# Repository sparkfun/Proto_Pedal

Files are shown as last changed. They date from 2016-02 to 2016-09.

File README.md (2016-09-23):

SparkFun Proto Pedal
========================================

SparkFun Proto Pedal

[*SparkFun Proto Pedal*](https://www.sparkfun.com/products/13124)

[*SparkFun Proto Pedal Chassis*](https://www.sparkfun.com/products/13967)

The SparkFun Proto Pedal is breatboard featuring prewired I/O boilerplate for building guitar stompboxes.  We also offer a matching predrilled chassis.

_**If you're looking for the Teensy Project Sketches**_ [they're here](https://github.com/sparkfun/Proto_Pedal/tree/master/projects/teensy-based).  Please remember to check the individual sketches for further notes and details in their respective `README.md` files.

Repository Contents
-------------------

* **/Hardware** - Eagle design files (.brd, .sch)
* **/Mechanical** - Enclosure files and related information
* **/Production** - Production panel files (.brd)
* **/Projects** - Example circuits build on the Proto Pedal <PRODUCT NAME>

Documentation
--------------
* **[Proto Pedal Assembly and Theory Guide](https://learn.sparkfun.com/tutorials/proto-pedal-assembly-and-theory-guide)** - Information to help get started.
* **[Chassis Hookup Guide](https://learn.sparkfun.com/tutorials/proto-pedal-chassis-hookup-guide)** - Drilling and painting the enclosure.
* **[Analog Equalizer Project](https://learn.sparkfun.com/tutorials/proto-pedal-example-analog-equalizer-project)** - the gyrator based two-band EQ example.
* **[Teensy-Audio based Programmable Digital Pedal](https://learn.sparkfun.com/tutorials/proto-pedal-example-programmable-digital-pedal)** - building a DSP development platform

Product Versions
----------------
* [SparkFun Proto Pedal](https://www.sparkfun.com/products/13124)
* [SparkFun Proto Pedal Chassis](https://www.sparkfun.com/products/13967)

Version History
---------------
* [441c191](https://github.com/sparkfun/Proto_Pedal/commit/441c1917a6b56c2a821627207be28ff88913c089) - Initial Release

License Information
-------------------

This product is _**open source**_!

Please review the LICENSE.md file for license information.

If you have any questions or concerns on licensing, please contact techsupport@sparkfun.com.

Distributed as-is; no warranty is given.

- Your friends at SparkFun.

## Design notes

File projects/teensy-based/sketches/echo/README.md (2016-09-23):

# Echo Pedal

This sketch runs on a Teensy that has been embeded into a proto pedal.

**Important**: build this in a non-optimized target mode.  We were using the plain 72 MHz mode.  If you feel strongly about optimization, you'll need to slightly decrease the delay buffer size, as specified by the LEN macro.  Optimization apparently trades RAM for execution speed.

The effect emulates a vintage style tape echo, by degenerating the repeats with hipass and lopass filters.  The delay feedback can to go above unity gain, and the lopass filter has a Q control, allowing buildup of repeat artifacts.

The demo expects 5 knobs:

* Delay length at A1 -- how long it takes new input to reach the output
* Feedback level at A7 -- controls the number of echoes
* Highpass frequency at A1 -- Feedback filter highpass frequency
* Highpass resonance at A6 -- Feedback filter highpass resonance, effectively a bass boost
* Lowpass frequency at A7 -- Feedback filter lowpass frequency

Iff'n ya build it with **6** knobs, then you've got a control for the Lowpass Q, too.

The Highpass resonance contributes to the feedback.  Both it and the feedback control can cause the effect to run away.

## Directory contents:

* echo.ino -- The sketch.  Requires teensyduino
* readme.md -- This file.
* mod-delay.cpp/.h -- the delay line object...not yet mature enough to be officially contributed to Teensy Audio.
* cubic-distort.cpp/.h -- a vestigial soft-clipping distortion block.

## Performance Notes

It can be a fun effect, but it's got some ugly details.

* The distortion in the feedback loop wasn't especially useful.  The mixers already use saturating math, so they hard clip.
* There's also a white noise block feeding the input mixer, but it's usually turned off.  It's possible to introduce an almost inaudible amount, to get it to run away with no other input.
* The delay line gets wonky & distorted if the modulation input is discontinuous.  We do several things to help smooth it.
  * We throw away the noisy bottom LSBs of that ADC channel.
  * We're using a DC block to generate the timing signal for the delay, and setting the ramp time parameter to be longer than necessary.  If you want to make things sound more rubbery, turn that time way up...
  * We keep track of the last value sent to that DC block, so we aren't calling it continually, resetting the time parameter.

There's also the issue of noise floor performance.  What we've learned so far

* Having the USB port connected contributes to the 60/120 Hz in the background.
* Having the USB port connected & talking to a serial app causes even more noise.

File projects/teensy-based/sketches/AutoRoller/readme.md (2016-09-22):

# AutoRoller Pedal

This sketch runs on a Teensy that has been embeded into a proto pedal.

The effect has an input filter for tone control, and output low-pass filter for effect, and a modulation source consisting of a sine wave generator with rate dependent on input peak values, so the louder you play the more wah-wahs happen.

The demo expects 5 knobs:

* Hi knob at A3 -- Input filter high tones
* Lo knob at A2 -- Input filter low tones
* Tone knob at A1 -- Output filter cutoff and resonance.  CCW is low filter high Q, CW is high filter low Q
* Depth knob at A6 -- Sets modulation depth
* Speed knob at A7 -- Sets modulation osc rate

Directory contents:

* AutoRoller.ino -- The sketch.  Requires teensyduino
* AutoRollerAudioProject.png -- A picture of the Audio Tool workspace
* AutoRollerAudioProject.txt -- The output data that corresponds with the graphic.  Note:  This may differ from the sketch but should always match the graphic.  This is so you can modify the sketch but still have the source Audio Tool project, until you are happy with the changes and the png/txt can be updated.
* readme.md -- This file.

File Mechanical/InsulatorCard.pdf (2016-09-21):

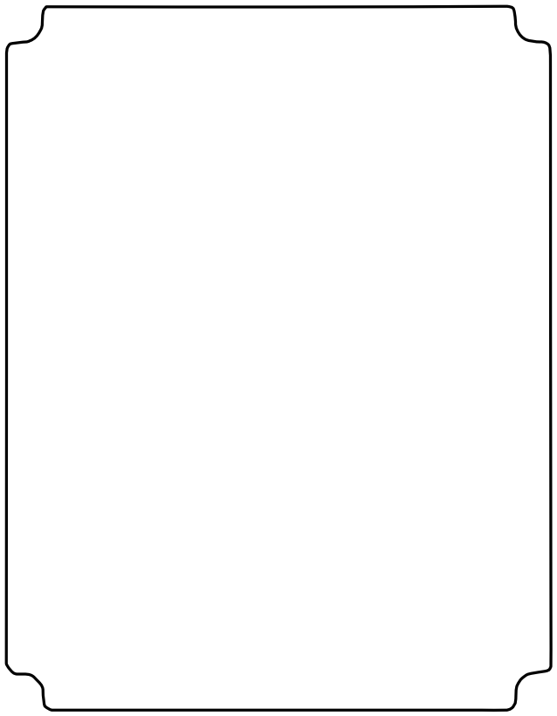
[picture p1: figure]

Proto Pedal Insulator Card

Select “Actual Size” when printing

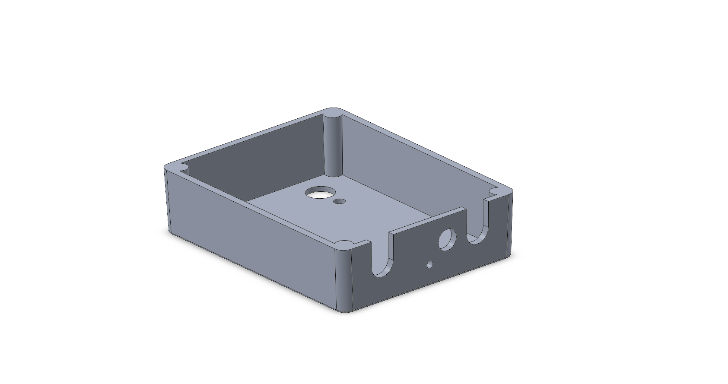
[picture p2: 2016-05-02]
Mechanical/solidworks/case_w_cutouts_model.PNG

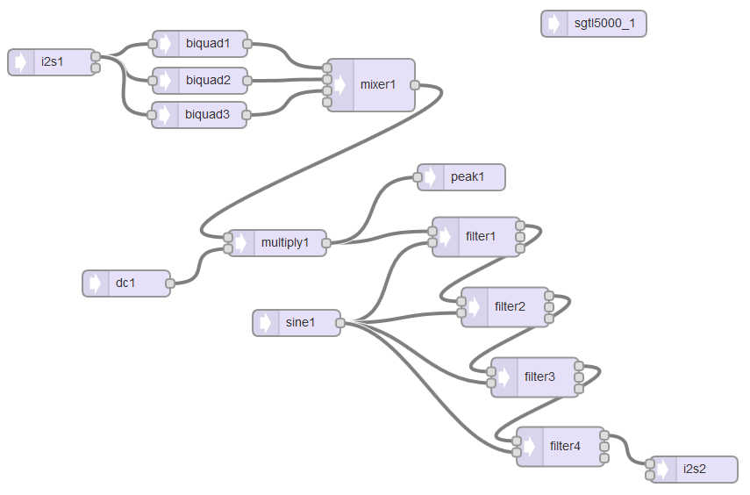
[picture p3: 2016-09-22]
projects/teensy-based/sketches/AutoRoller/AutoRollerAudioProject.png

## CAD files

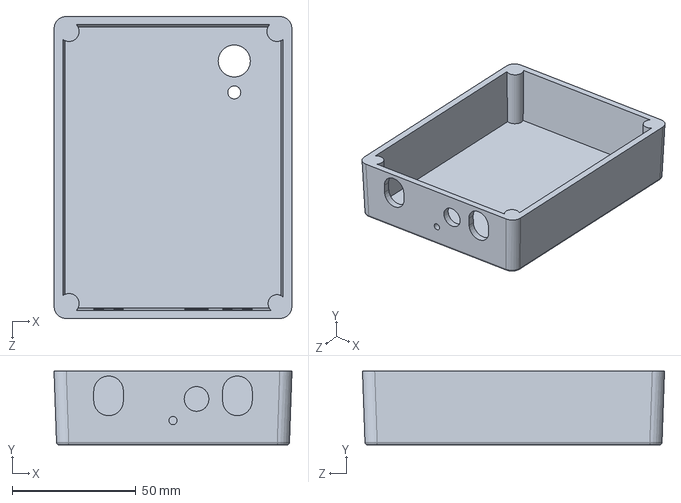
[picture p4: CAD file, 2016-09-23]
Mechanical/solidworks/case_w_cutouts_model_2.SLDPRT
96.2 x 29.8 x 122.1 mm

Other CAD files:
Mechanical/CaseWCutoutsModel.FCStd

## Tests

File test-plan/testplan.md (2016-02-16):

#Proto Pedal Test Plan.

## Prologue

Assemble the protopedal by soldering the PTH components to the PCB.  If you're intending to interface with a case, it's best to use the case as an assembly jig, to hold the TRS jacks and stomp switch.  Be sure the following have been connected:

* 2x TRS jacks
* 9V battery snap with regard for color coding.
* Barrel jack.

## Background

*The stuff it's easy to forget when testing this device*

Power circuits are completed by connecting a 1/4" TS jack  to the input terminal.  The sleeve of the jack bridges the ring terminal to ground, completing the power circuit.

The barrel jack is sleeve-positive, tip-negative, as per the Roland/Boss standard.

The barrel jack should disconnect the 9V battery when it's connected.  We'll test this below!

## Materials

* Multimeter with continuity, VDC and IDC modes.
* Adjustable DC power supply with alligator clip wires and Ammeter display. 
	* If not stated in test, configure supply for 9VDC output, with 25 mA current limit.   
* Barrel jack to raw wire pigtail, with *tip* and *barrel* clearly marked.
* 1/4" TS jack (this can be a loose jack, or on a TS cable).  *Be certain that it is not a TRS jack!*

## Power Related Tests

1. Sanity check against obvious shorts
	* Measure continuity between VCC and ground pads.
	* **Criteria:** should read open-circuit from VCC to Ground. 

2. Verify input jack form ground connection
	* Measure continuity from TP4 (input ring, adjacent to input test point) to GND.
	* **Criteria:**  should measure open.
	* Connect TS jack to input.
	* Measure continuity from TP4 to GND.
	* **Criteria:** Should measure short.

3. Verify VAUX is floating
	* Measure continuity from Vaux to VCC
	* **Criteria:** should measure open
	* Measure continuity from Vaux to GND
	* **Criteria:** should measure open 

3. Verify battery snap polarity.
	* Connect power supply to 9V battery snap.  
		* The larger terminal is +V
		* The smaller terminal is ground
	* Set power supply to current limit at 25 mA.
	* Switch supply on. 
	* **Criteria:** Supply should indicate no current flowing.
	* Connect 1/4" TS jack to input.
	* Measure voltage between VCC and GND.
	* **Criteria:** Should measure supply voltage between VCC and GND
	* Switch the stomp switch.
	* **Criteria:** SMT LED should toggle on and off
	* **Criteria:** While LED is on, supply current should read ~5 mA.
	* Turn power supply off, remove input jack, disconnect battery snap.

4.  Verify 9V battery reverse polarity protection
	* Connect power supply to 9V battery snap, now reversed.  
		* The larger terminal is Ground
		* The smaller terminal is +V
	* Set power supply to current limit at 25 mA.
	* Switch supply on. 
	* **Criteria:** Supply should indicate no current flowing.
	* Connect 1/4" TS jack to input.
	* Measure voltage between VCC and GND.
	* **Criteria:** Should measure at most 10 mV DC, supply indicating no measurable current.
	* Switch the stomp switch.
	* **Criteria:** SMT LED should remain dark
	* Turn power supply off, remove input jack, disconnect battery snap.

5. Verify barrel jack polarity.
	* Connect power supply to barrel jack with pigtails  
		* Barrel is +V
		* Tip is ground
	* Set power supply to current limit at 25 mA.
	* Switch supply on. 
	* **Criteria:** Supply should indicate no current flowing.
	* Connect 1/4" TS jack to input.
	* Measure voltage between VCC and GND.
	* **Criteria:** Should measure supply voltage between VCC and GND
	* Switch the stomp switch.
	* **Criteria:** SMT LED should toggle on and off
	* **Criteria:** While LED is on, supply current should read ~5 mA.
	* Turn power supply off, remove input jack, disconnect battery snap.

6. Verify barrel jack reverse polarity protection
	* Connect power supply to barrel jack with pigtails  
		* Barrel is ground
		* Tip is +V
	* Set power supply to current limit at 25 mA.
	* Switch supply on. 
	* **Criteria:** Supply should indicate no current flowing.
	* Connect 1/4" TS jack to input.
	* Measure voltage between VCC and GND.
	* **Criteria:** Should measure at most 10 mV DC, supply indicating no measurable current.
	* Switch the stomp switch.
	* **Criteria:** SMT LED should remain dark
	* Turn power supply off, remove input jack, disconnect battery snap.

7. Verify Barrel Jack Defeats battery. 
	* Connect power supply to 9V battery snap.  
		* The larger terminal is +V
		* The smaller terminal is ground
	* Disconnect barrel jack pigtails from all connections 
	* Insert TS jack into input.
	* Toggle stomp switch until SMT LED comes on.
	* **Criteria:** Supply should indicate ~5 mA DC draw.
	* Insert disconnected barrel into socket.
	* **Criteria:** Supply should indicate 0 mA, LED should go dark.
	* Remove barrel from socket.
	* **Criteria:** LED should illuminate, current returns to ~5 mA. 
 
8. Verify Power Input Range
	* Connect power supply to barrel jack with pigtails  
		* Barrel is +V
		* Tip is ground
	* Plug TS into input.
	* Turn on power supply at 9 VDC.
	* Toggle stomp switch until LED comes on.
	* Slowly ramp PSU up to 18 VDC.
	* **Criteria:** No catastrophic failure, excess heat or excess current draw (typical current draw will be about ~15 mA).  
	
## Switching Related Tests.

1. Prerequesite configuration
	* These teses assume that the DUT has already passed the power section tests.  They also share a common setup:
		* TS connector plugged into intput jack.
		* 9VDC connected via barrel connector
			* barrel is +9VDC
			* tip is ground
		* These tests will call for DUT to switch between active and bypass states.  The SMT LED is illuminated when the DUT is in the active state. 

1. Verify Bypass state is functional
	* Set switch to bypass. SMT LED will be off.
	* Measure resistance from input tip connection to left side of C1 (at lower left corner of PCB) 
	* **Criteria:** External side of C1 is floating WRT input tip
	* Measure resistance from input tip to output tip.
	* **Criteria:** tip-to-tip shows continuity.
	* Measure resistance from left side of C1 to ground
	* **Criteria:** LHS of C1 continuous with ground
	* Measure RHS of C2  (adjacent to battery leads) to tip of output
	* **Criteria:** RHS of C2 is floating WRT output tip
	* Measure RHS of C2 to ground
	* **Criteria:** RHS of C2 is 1Meg to ground.  
	* 
2. Verify active state is functional
	* Set switch to active state.  SMT LED will illuminate
	* Measure voltage between RHS of R4 (PTH resistor marked "BRT") and ground
	* **Criteria:** Vcc (~9VDC) present at RHS of R4.
	* Measure resistance from input tip to ground.
	* **Criteria:** Input tip is is 1Meg to ground.  
	* Measure resistance from input tip to LHS C1.
	* **Criteria:** Input tip is contonuous with LHS C1
	* Measure resistance input tip to output tip
	* **Criteria:** Resistance tip-to-tip is 2 Meg.
	* Measure resistance RHS of C2 to output tip
	* **Criteria:** Output tip is contonuous with RHS C2
	* Measure resistance output tip to ground 
	* **Criteria:** Output tip is is 1Meg to ground.
3. Verify SJ1 defeats SMT LED.
	* Remove power.
	* Clear solder jumper SJ1

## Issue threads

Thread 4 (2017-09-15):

Error compiling for Teensy 3.2 in Arduino 1.6.133

mswartz, 2017-09-15:
Hi, thanks for a fun tutorial! Got the hardware running, am trying to use some of the software examples. Throughput works fine, but I'm running into this problem with the echo sketch:

```echo: In function 'void loop()':
echo:178: warning: unused variable 'next_on'
   static bool next_on = true;
               ^
/Applications/Arduino.app/Contents/Java/hardware/tools/arm/bin/../lib/gcc/arm-none-eabi/4.8.4/../../../../arm-none-eabi/bin/ld: /var/folders/t2/8mc1sfxx51d39b6_826qt5c00000gn/T/arduino_build_49085/echo.ino.elf section `.bss' will not fit in region `RAM'
/Applications/Arduino.app/Contents/Java/hardware/tools/arm/bin/../lib/gcc/arm-none-eabi/4.8.4/../../../../arm-none-eabi/bin/ld: region `RAM' overflowed by 1280 bytes
collect2: error: ld returned 1 exit status
Multiple libraries were found for "SD.h"
 Used: /Applications/Arduino.app/Contents/Java/hardware/teensy/avr/libraries/SD
 Not used: /Applications/Arduino.app/Contents/Java/libraries/SD
Error compiling for board Teensy 3.2 / 3.1.```

Any ideas for how to fix this?

Jacquot-SFE, 2017-09-15:
I've seen this before.  Two things to try.

First, make sure you've got a non-optimized target selected in the "tools->cpu speed" menu.  The optimized builds supposedly run faster, but use more RAM.  You don't need the computational cycles, but more RAM means longer max delay time, which you probably _do_ want.

Second, if that fails (the internals may have changed since I wrote the sketch), take the number in the error message (ie: the 1280 bytes), and subtract it from the LEN constant.

mswartz, 2017-09-15:
Ah, thanks! I reduced LEN to `0x06300` and it worked, albeit with a low memory warning. Thanks for the quick help.

mswartz, 2017-09-15:
Also just confirmed that changing the CPU speed works as well. Great tips, thanks!

Closed 2017-09-15.

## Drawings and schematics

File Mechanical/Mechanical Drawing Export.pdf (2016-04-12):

# FRONT VIEW (VORDERSEITE)

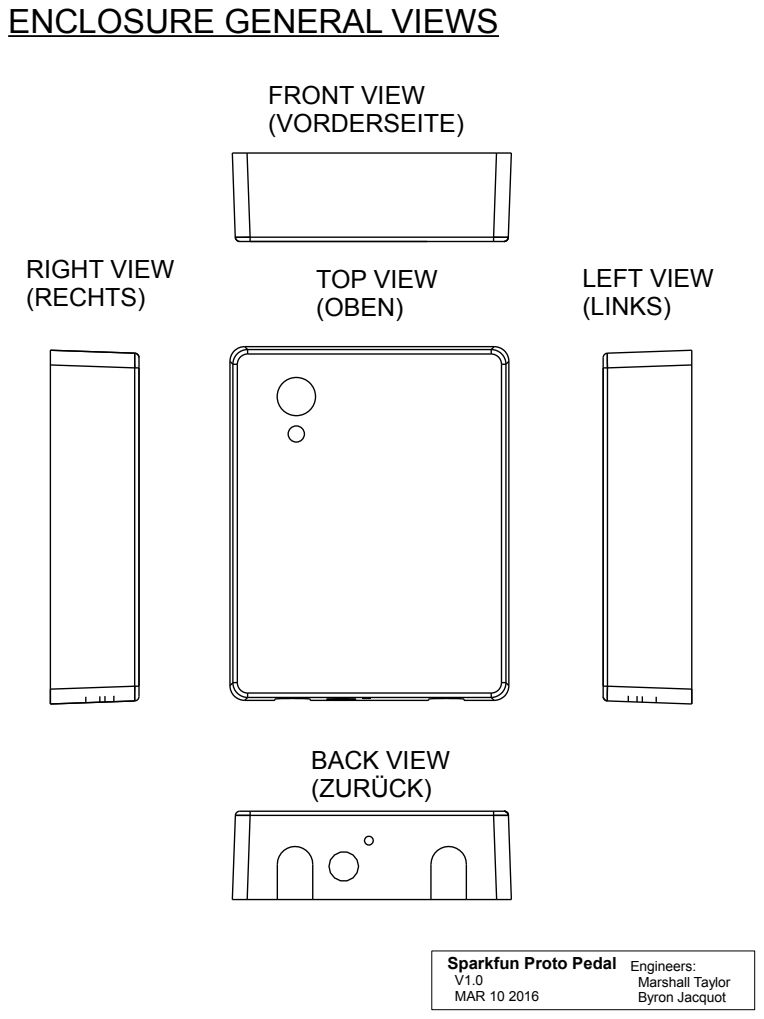
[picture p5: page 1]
RIGHT VIEW (RECHTS); LEFT VIEW (LINKS); BACK VIEW (ZURÜCK); TOP VIEW (OBEN); Engineers: Marshall Taylor Byron Jacquot; Sparkfun Proto Pedal V1.0 MAR 10 2016

ENCLOSURE GENERAL VIEWS

# ENCLOSURE DETAIL

# TOP VIEW

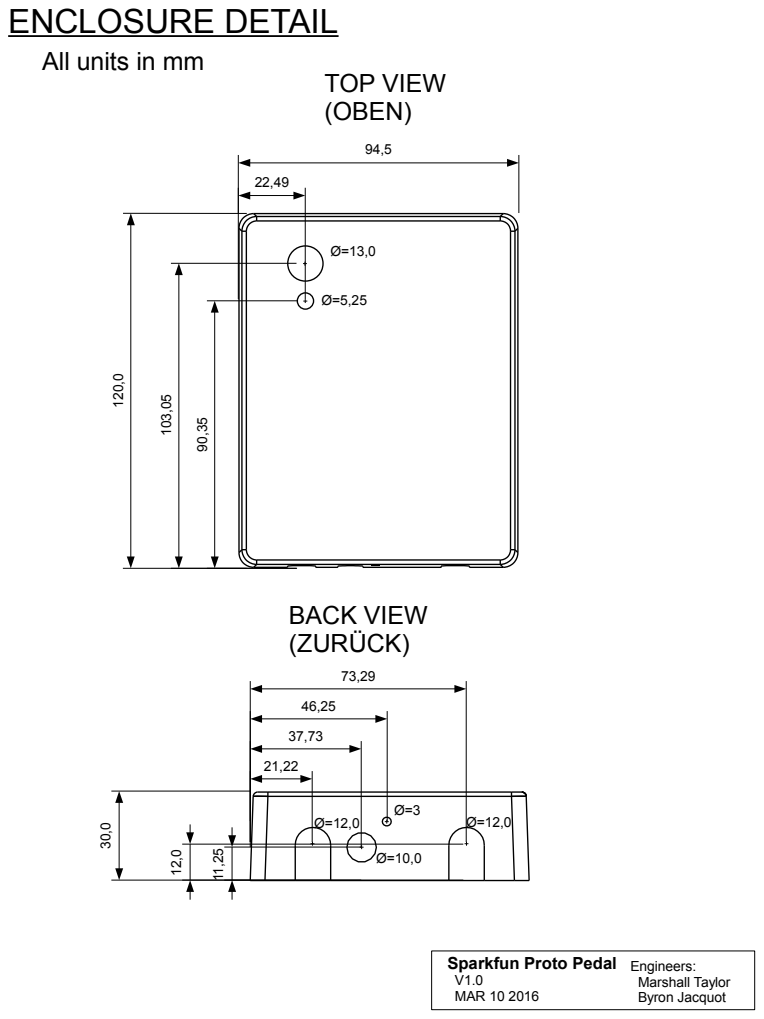
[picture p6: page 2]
BACK VIEW (ZURÜCK); (OBEN); Engineers: Marshall Taylor Byron Jacquot; Sparkfun Proto Pedal V1.0 MAR 10 2016

All units in mm

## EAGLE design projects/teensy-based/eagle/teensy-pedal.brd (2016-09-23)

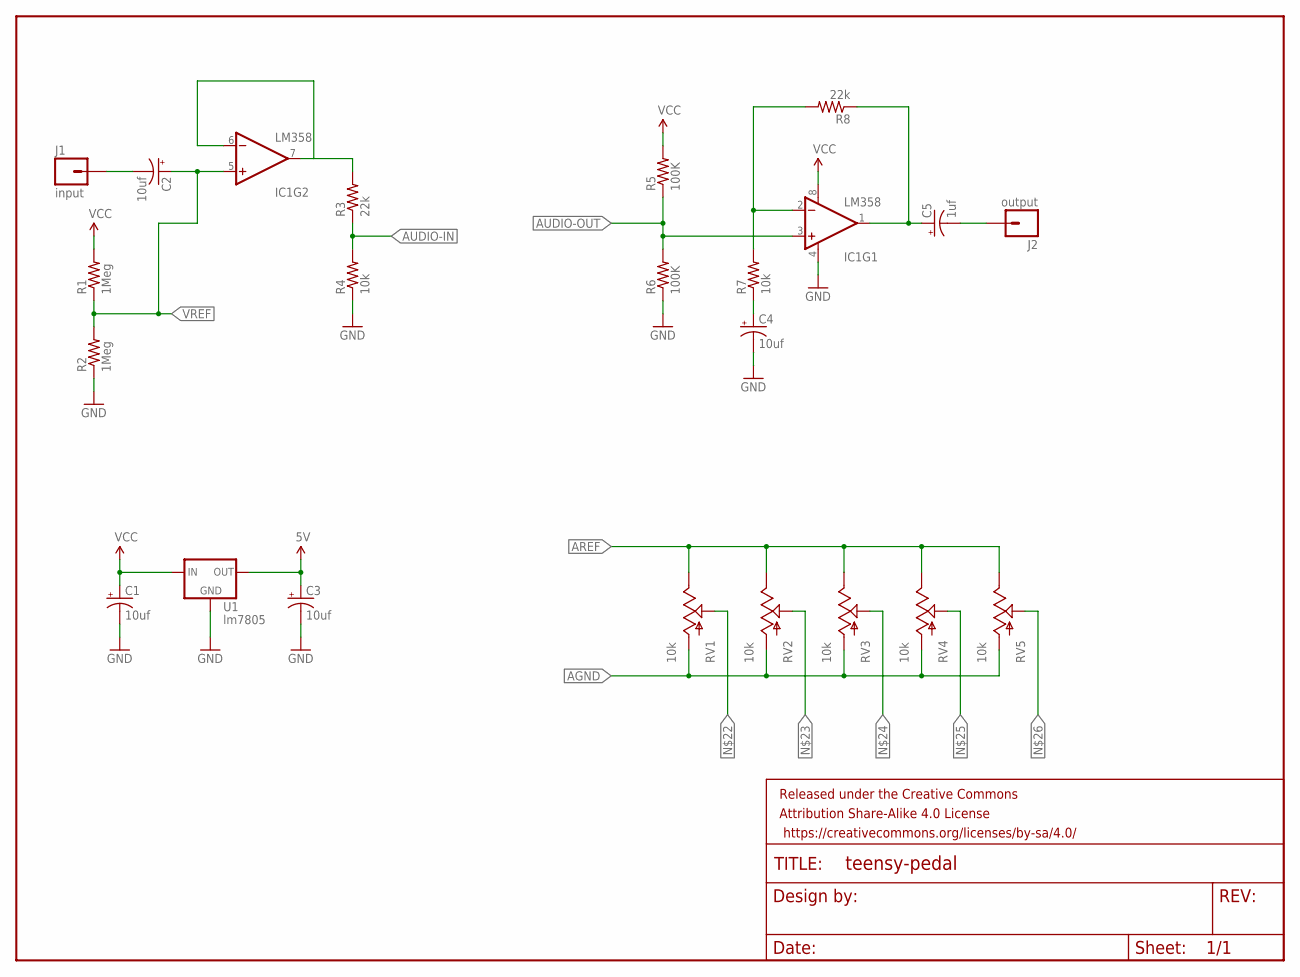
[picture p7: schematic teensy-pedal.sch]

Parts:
C1, C2, C3, C4: 10uf; CPOL-RADIAL-10UF-25V
C5: 1uf; CPOL-RADIAL-10UF-25V
FRAME1: FRAME-LETTER; CREATIVE_COMMONS
IC1: LM358; DIP08
J1: input; 1X01NS-KIT
J2: output; 1X01NS-KIT
R1, R2: 1Meg; AXIAL-0.3
R3, R8: 22k; AXIAL-0.3
R4, R7: 10k; AXIAL-0.3
R5, R6: 100K; AXIAL-0.3
RV1, RV2, RV3, RV4, RV5: 10k; POT_ALPHA_RV16AF-20
U1: lm7805; TO-220-ALT

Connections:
5V: C3.1 (+), U1.OUT
AGND: RV1.1 (A), RV2.1 (A), RV3.1 (A), RV4.1 (A), RV5.1 (A)
AREF: RV1.3 (E), RV2.3 (E), RV3.3 (E), RV4.3 (E), RV5.3 (E)
AUDIO-IN: R3.P$1 (1), R4.P$2 (2)
AUDIO-OUT: IC1.3 (+IN), R5.P$1 (1), R6.P$2 (2)
GND: C1.2 (-), C3.2 (-), C4.2 (-), IC1.4 (V-), R2.P$1 (1), R4.P$1 (1), R6.P$1 (1), U1.GND
unnamed: C5.1 (+), IC1.1 (OUT), R8.P$1 (1)
unnamed: IC1.6 (-IN), IC1.7 (OUT), R3.P$2 (2)
unnamed: IC1.2 (-IN), R7.P$2 (2), R8.P$2 (2)
unnamed: C2.2 (-), J1.1
unnamed: C5.2 (-), J2.1
unnamed: C4.1 (+), R7.P$1 (1)
VCC: C1.1 (+), IC1.8 (V+), R1.P$2 (2), R5.P$2 (2), U1.IN
VREF: C2.1 (+), IC1.5 (+IN), R1.P$1 (1), R2.P$2 (2)

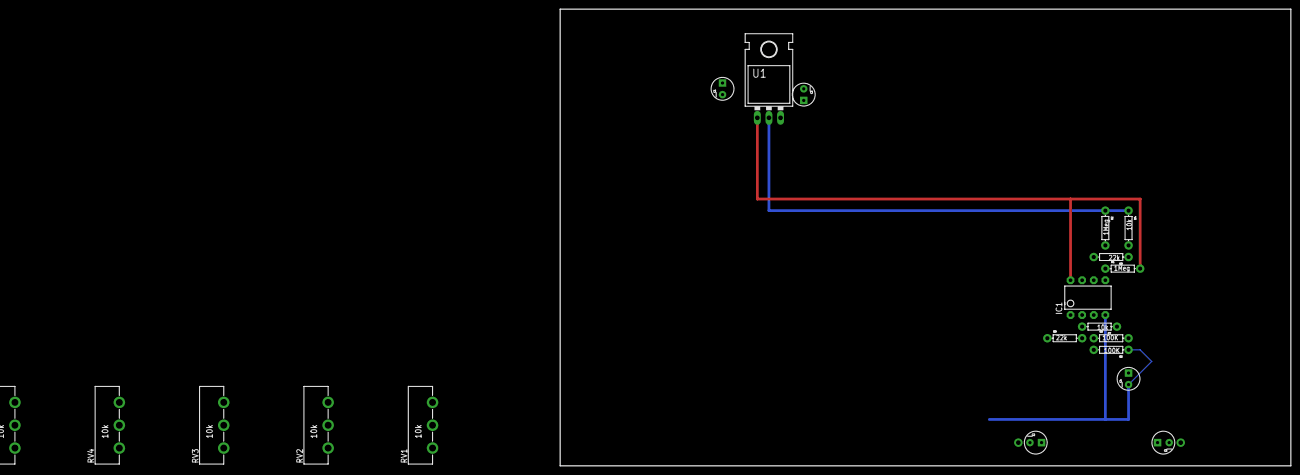
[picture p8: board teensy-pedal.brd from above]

Board: 2 copper layers, 160.0 x 100.0 mm, 23 parts (0 on the bottom side), 14 nets.

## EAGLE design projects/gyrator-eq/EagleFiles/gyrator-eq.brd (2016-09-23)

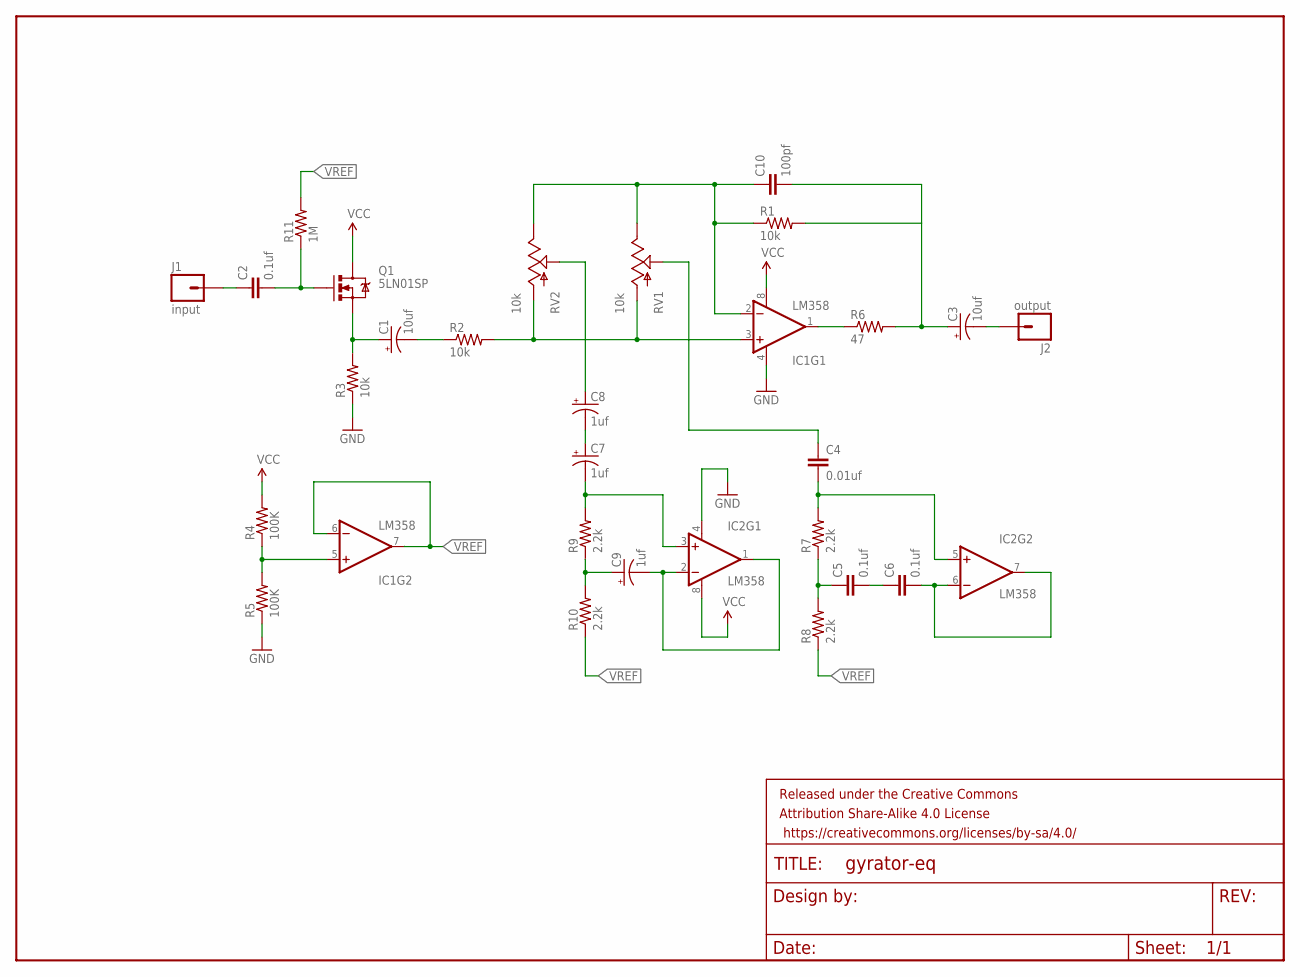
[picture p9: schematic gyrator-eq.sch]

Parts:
C1, C3: 10uf; CPOL-RADIAL-10UF-25V
C2: 0.1uf; CAP-PTH-SMALL-KIT
C4: 0.01uf; CAP-PTH-SMALL
C5, C6: 0.1uf; CAP-PTH-SMALL
C7, C8, C9: 1uf; CPOL-RADIAL-10UF-25V
C10: 100pf; CAP-PTH-SMALL
FRAME1: FRAME-LETTER; CREATIVE_COMMONS
IC1, IC2: LM358; DIP08
J1: input; 1X01NS-KIT
J2: output; 1X01NS-KIT
Q1: 5LN01SP; TO-92-AMMO
R1, R2, R3: 10k; AXIAL-0.3
R4, R5: 100K; AXIAL-0.3
R6: 47; AXIAL-0.3
R7, R8, R9, R10: 2.2k; AXIAL-0.3
R11: 1M; AXIAL-0.3
RV1, RV2: 10k; POT_ALPHA_RV16AF-20

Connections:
GND: IC1.4 (V-), IC2.4 (V-), R3.P$1 (1), R5.P$1 (1)
unnamed: C2.2, Q1.3 (G), R11.P$1 (1)
unnamed: C1.1 (+), Q1.1 (S), R3.P$2 (2)
unnamed: C1.2 (-), R2.P$1 (1)
unnamed: IC1.3 (+IN), R2.P$2 (2), RV1.1 (A), RV2.1 (A)
unnamed: IC1.1 (OUT), R6.P$1 (1)
unnamed: C3.1 (+), C10.2, R1.P$2 (2), R6.P$2 (2)
unnamed: C10.1, IC1.2 (-IN), R1.P$1 (1), RV1.3 (E), RV2.3 (E)
unnamed: IC1.5 (+IN), R4.P$1 (1), R5.P$2 (2)
unnamed: C2.1, J1.1
unnamed: C8.1 (+), RV2.2 (S)
unnamed: C7.1 (+), C8.2 (-)
unnamed: C7.2 (-), IC2.3 (+IN), R9.P$2 (2)
unnamed: C9.1 (+), R9.P$1 (1), R10.P$2 (2)
unnamed: C4.1, RV1.2 (S)
unnamed: C6.2, IC2.6 (-IN), IC2.7 (OUT)
unnamed: C9.2 (-), IC2.1 (OUT), IC2.2 (-IN)
unnamed: C4.2, IC2.5 (+IN), R7.P$2 (2)
unnamed: C5.2, C6.1
unnamed: C5.1, R7.P$1 (1), R8.P$2 (2)
unnamed: C3.2 (-), J2.1
VCC: IC1.8 (V+), IC2.8 (V+), Q1.2 (D), R4.P$2 (2)
VREF: IC1.6 (-IN), IC1.7 (OUT), R8.P$1 (1), R10.P$1 (1), R11.P$2 (2)

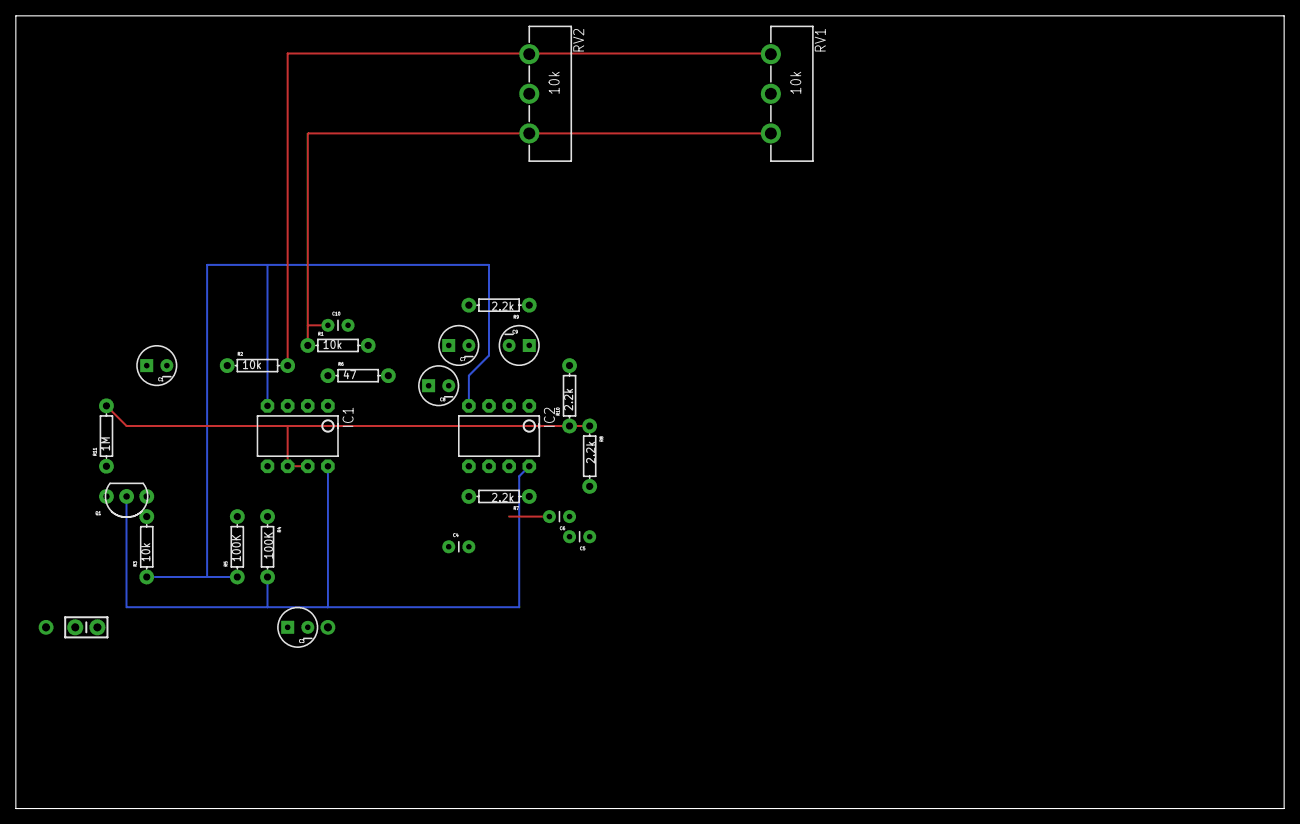
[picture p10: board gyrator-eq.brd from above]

Board: 2 copper layers, 160.0 x 100.0 mm, 29 parts (0 on the bottom side), 23 nets.

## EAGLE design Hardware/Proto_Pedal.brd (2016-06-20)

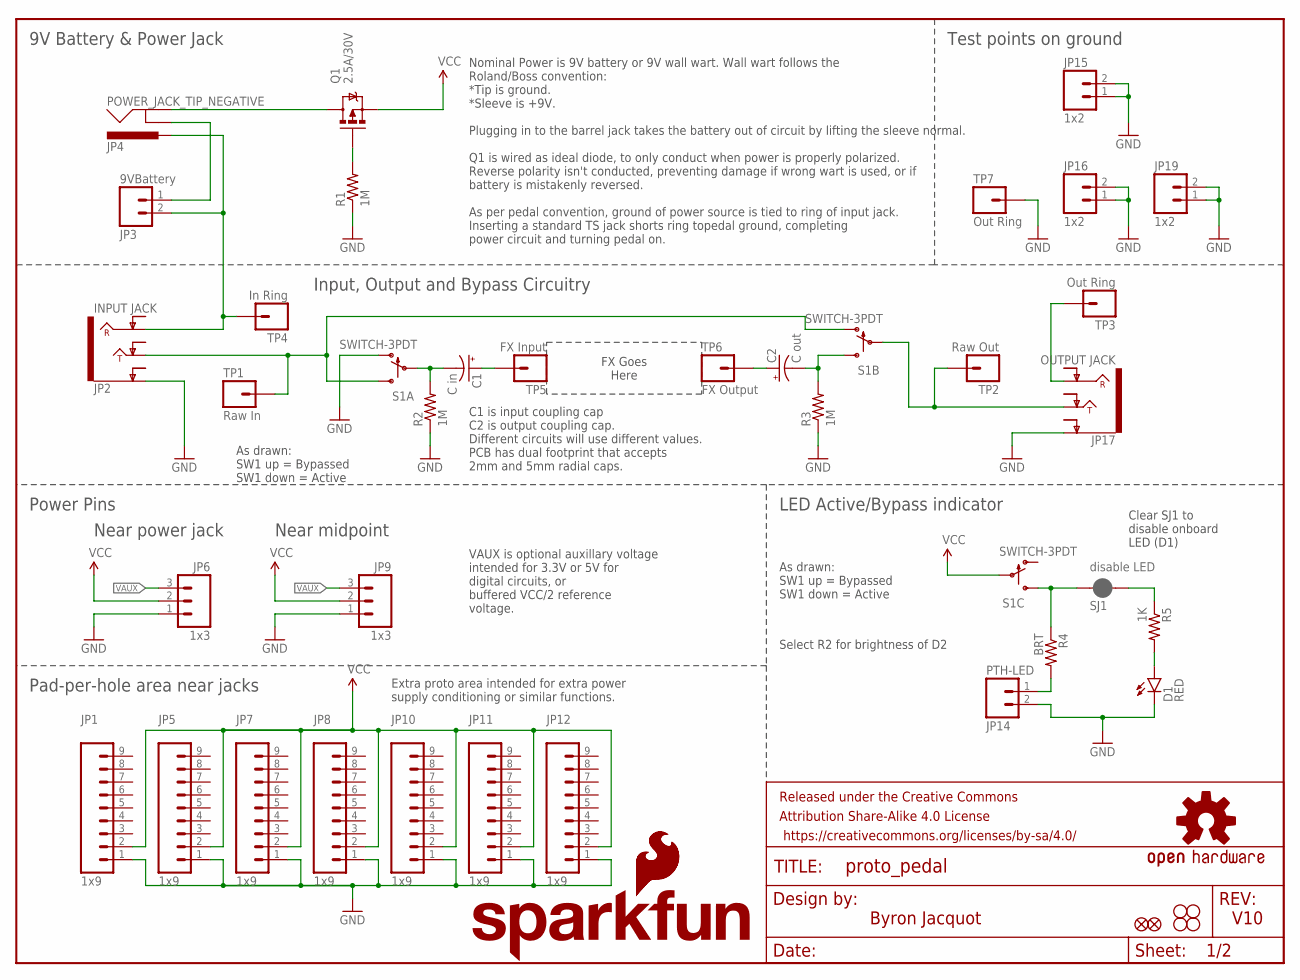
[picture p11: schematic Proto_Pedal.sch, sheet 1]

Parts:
C1: C in; DUAL-CAP
C2: C out; DUAL-CAP
D1: RED; LED-0603
FID1, FID2: FIDUCIAL1X2; FIDUCIAL-1X2
FRAME1: FRAME-LETTER; CREATIVE_COMMONS
JP1, JP5, JP7, JP8, JP10, JP11, JP12: 1x9; 1X09_NO_SILK
JP2: INPUT JACK; AUDIO-JACK-.25-INCH-HORIZ-PTH
JP3: 9VBattery; 1X02_LONGPADS
JP4: POWER_JACK_TIP_NEGATIVE; POWER-BARRELJACK-PTH-LOCK-FIXED
JP6, JP9: 1x3; 1X03_NO_SILK
JP14: PTH-LED; 1X02_LONGPADS
JP15, JP16, JP19: 1x2; 1X02_NO_SILK
JP17: OUTPUT JACK; AUDIO-JACK-.25-INCH-HORIZ-PTH
LOGO1: SFE_LOGO_NAME_FLAME.2_INCH; SFE_LOGO_NAME_FLAME_.2
LOGO2: OSHW-LOGOL; OSHW-LOGO-L
LOGO3: SFE_LOGO_FLAME.2_INCH; SFE_LOGO_FLAME_.2
Q1: 2.5A/30V; SOT23-3
R1, R2, R3: 1M; 0603-RES
R4: BRT; AXIAL-0.3
R5: 1K; 0603-RES
S1: SWITCH-3PDT; STOMP-SWITCH-3PDT
SJ1: disable LED; PAD-JUMPER-2-NC_BY_PASTE_YES_SILK_FULL_BOX
STANDOFF1, STANDOFF2, STANDOFF3, STANDOFF4: STAND-OFF
TP1: Raw In; 1X01_NO_SILK
TP2: Raw Out; 1X01_NO_SILK
TP3: Out Ring; 1X01_NO_SILK
TP4: In Ring; 1X01_NO_SILK
TP5: FX Input; 1X01_NO_SILK
TP6: FX Output; 1X01_NO_SILK
TP7: Out Ring; 1X01_LONGPAD

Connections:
FX_IN: C1.P$2 (-), C1.P$3 (-), R2.2, S1.P$2
FX_OUT: C2.P$2 (-), C2.P$3 (-), R3.2, S1.P$6 (S)
GND: D1.C, JP1.1, JP2.SLEEVE (EARTH), JP5.1, JP6.1, JP7.1, JP8.1, JP9.1, JP10.1, JP11.1, JP12.1, JP14.2, JP15.1, JP15.2, JP16.1, JP16.2, JP17.SLEEVE (EARTH), JP19.1, JP19.2, R1.1, R2.1, R3.1, S1.P$1 (O), TP7.1; also elsewhere on the board
LEDA: JP14.1, R4.P$2 (2)
unnamed: D1.A, R5.2
unnamed: R4.P$1 (1), S1.P$9 (S), SJ1.1
unnamed: JP3.1, JP4.SLEEVE-NORMAL (SLEEVEBREAK)
unnamed: JP2.RING, JP3.2, JP4.TIP, TP4.1
unnamed: R5.1, SJ1.2
unnamed: JP17.RING, TP3.1
unnamed: C1.P$1 (+), TP5.1
unnamed: C2.P$1 (+), TP6.1
unnamed: JP2.TIP, S1.P$3 (S), S1.P$4 (O), TP1.1
unnamed: JP17.TIP, S1.P$5, TP2.1
unnamed: Q1.1 (G), R1.2
VAUX: JP6.3, JP9.3
VBATT: JP4.SLEEVE, Q1.3 (D)
VCC: JP1.2, JP5.2, JP6.2, JP7.2, JP8.2, JP9.2, JP10.2, JP11.2, JP12.2, Q1.2 (S), S1.P$8; also elsewhere on the board

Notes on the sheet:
Byron Jacquot
V10
Power Pins
Near midpoint
Clear SJ1 to disable onboard LED (D1)
As drawn: SW1 up = Bypassed SW1 down = Active
Test points on ground
FX Goes Here
9V Battery & Power Jack
Input, Output and Bypass Circuitry
Near power jack
LED Active/Bypass indicator
Pad-per-hole area near jacks
Nominal Power is 9V battery or 9V wall wart. Wall wart follows the Roland/Boss convention: *Tip is ground. *Sleeve is +9V. Plugging in to the barrel jack takes the battery out of circuit by lifting the sleeve normal. Q1 is wired as ideal diode, to only conduct when power is properly polarized. Reve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
VAUX is optional auxillary voltage intended for 3.3V or 5V for digital circuits, or buffered VCC/2 reference voltage.
Extra proto area intended for extra power supply conditioning or similar functions.
C1 is input coupling cap C2 is output coupling cap. Different circuits will use different values. PCB has dual footprint that accepts 2mm and 5mm radial caps.
Select R2 for brightness of D2

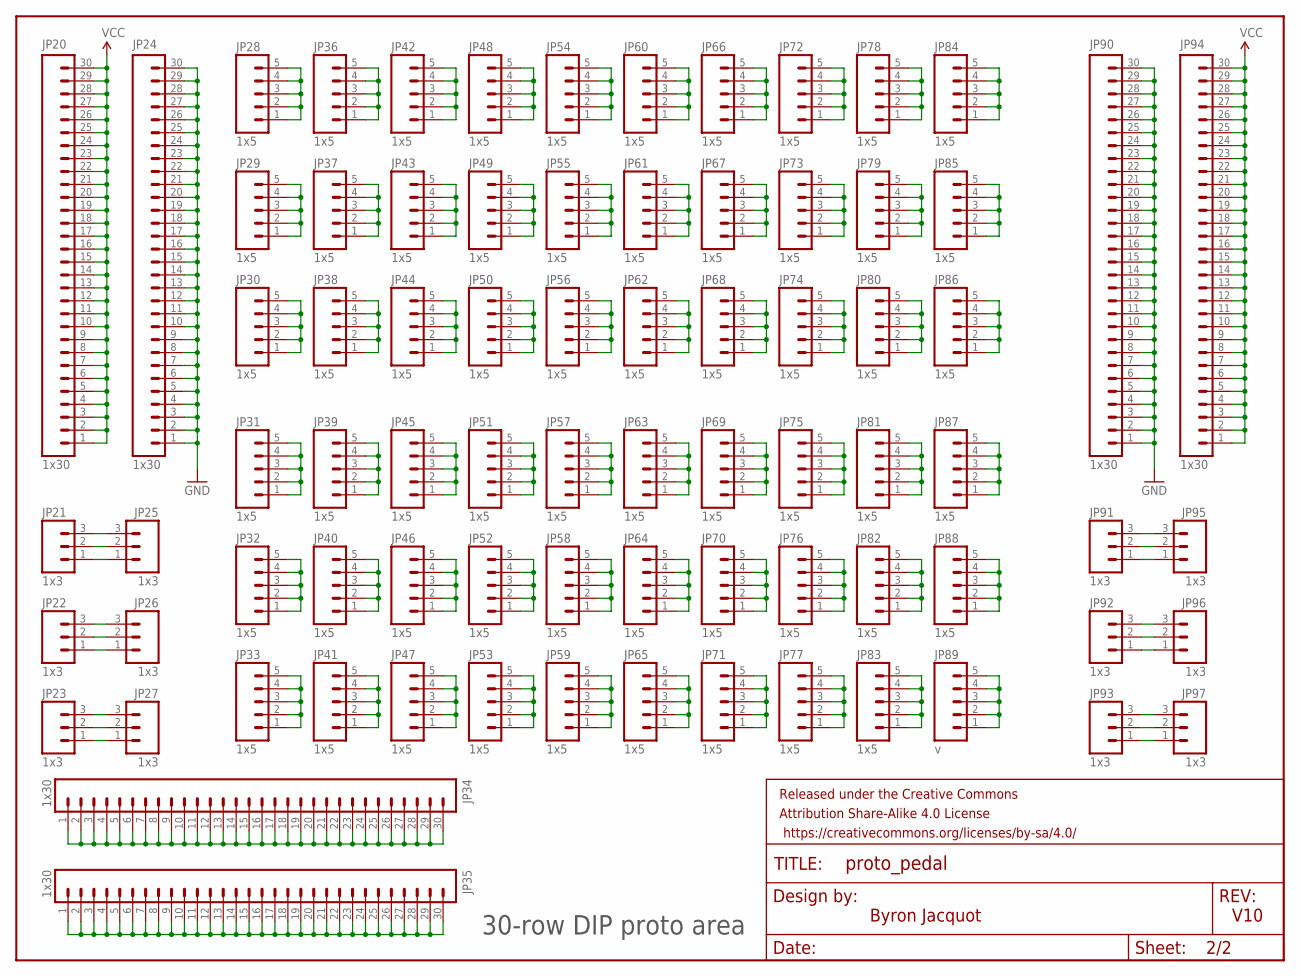
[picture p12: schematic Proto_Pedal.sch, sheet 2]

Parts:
FRAME2: FRAME-LETTER; CREATIVE_COMMONS
JP20, JP24, JP34, JP35, JP90, JP94: 1x30; 1X30_NO_SILK
JP21, JP22, JP23, JP25, JP26, JP27, JP91, JP92, JP93, JP95, JP96, JP97: 1x3; 1X03_NO_SILK
JP28, JP29, JP30, JP31, JP32, JP33, JP36, JP37, JP38, JP39, JP40, JP41, JP42, JP43, JP44, JP45, JP46, JP47, JP48, JP49, JP50, JP51, JP52, JP53, JP54, JP55, JP56, JP57, JP58, JP59, JP60, JP61, JP62, JP63, JP64, JP65, JP66, JP67, JP68, JP69, JP70, JP71, JP72, JP73, JP74, JP75, JP76, JP77, JP78, JP79, JP80, JP81, JP82, JP83, JP84, JP85, JP86, JP87, JP88: 1x5; 1X05_NO_SILK
JP89: v; 1X05_NO_SILK

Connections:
GND: JP24.1, JP24.2, JP24.3, JP24.4, JP24.5, JP24.6, JP24.7, JP24.8, JP24.9, JP24.10, JP24.11, JP24.12, JP24.13, JP24.14, JP24.15, JP24.16, JP24.17, JP24.18, JP24.19, JP24.20, JP24.21, JP24.22, JP24.23, JP24.24, JP24.25, JP24.26, JP24.27, JP24.28, JP24.29, JP24.30, JP90.1, JP90.2, JP90.3, JP90.4, JP90.5, JP90.6, JP90.7, JP90.8, JP90.9, JP90.10, JP90.11, JP90.12, JP90.13, JP90.14, JP90.15, JP90.16, JP90.17, JP90.18, JP90.19, JP90.20, JP90.21, JP90.22, JP90.23, JP90.24, JP90.25, JP90.26, JP90.27, JP90.28, JP90.29, JP90.30; also elsewhere on the board
unnamed: JP84.1, JP84.2, JP84.3, JP84.4, JP84.5
unnamed: JP85.1, JP85.2, JP85.3, JP85.4, JP85.5
unnamed: JP86.1, JP86.2, JP86.3, JP86.4, JP86.5
unnamed: JP87.1, JP87.2, JP87.3, JP87.4, JP87.5
unnamed: JP54.1, JP54.2, JP54.3, JP54.4, JP54.5
unnamed: JP88.1, JP88.2, JP88.3, JP88.4, JP88.5
unnamed: JP78.1, JP78.2, JP78.3, JP78.4, JP78.5
unnamed: JP72.1, JP72.2, JP72.3, JP72.4, JP72.5
unnamed: JP66.1, JP66.2, JP66.3, JP66.4, JP66.5
unnamed: JP60.1, JP60.2, JP60.3, JP60.4, JP60.5
unnamed: JP48.1, JP48.2, JP48.3, JP48.4, JP48.5
unnamed: JP42.1, JP42.2, JP42.3, JP42.4, JP42.5
unnamed: JP36.1, JP36.2, JP36.3, JP36.4, JP36.5
unnamed: JP28.1, JP28.2, JP28.3, JP28.4, JP28.5
unnamed: JP89.1, JP89.2, JP89.3, JP89.4, JP89.5
unnamed: JP79.1, JP79.2, JP79.3, JP79.4, JP79.5
unnamed: JP73.1, JP73.2, JP73.3, JP73.4, JP73.5
unnamed: JP67.1, JP67.2, JP67.3, JP67.4, JP67.5
unnamed: JP61.1, JP61.2, JP61.3, JP61.4, JP61.5
unnamed: JP55.1, JP55.2, JP55.3, JP55.4, JP55.5
unnamed: JP49.1, JP49.2, JP49.3, JP49.4, JP49.5
unnamed: JP43.1, JP43.2, JP43.3, JP43.4, JP43.5
unnamed: JP37.1, JP37.2, JP37.3, JP37.4, JP37.5
unnamed: JP29.1, JP29.2, JP29.3, JP29.4, JP29.5
unnamed: JP80.1, JP80.2, JP80.3, JP80.4, JP80.5
unnamed: JP74.1, JP74.2, JP74.3, JP74.4, JP74.5
unnamed: JP68.1, JP68.2, JP68.3, JP68.4, JP68.5
unnamed: JP62.1, JP62.2, JP62.3, JP62.4, JP62.5
unnamed: JP56.1, JP56.2, JP56.3, JP56.4, JP56.5
unnamed: JP50.1, JP50.2, JP50.3, JP50.4, JP50.5
unnamed: JP44.1, JP44.2, JP44.3, JP44.4, JP44.5
unnamed: JP38.1, JP38.2, JP38.3, JP38.4, JP38.5
unnamed: JP30.1, JP30.2, JP30.3, JP30.4, JP30.5
unnamed: JP81.1, JP81.2, JP81.3, JP81.4, JP81.5
unnamed: JP75.1, JP75.2, JP75.3, JP75.4, JP75.5
unnamed: JP69.1, JP69.2, JP69.3, JP69.4, JP69.5
unnamed: JP63.1, JP63.2, JP63.3, JP63.4, JP63.5
unnamed: JP57.1, JP57.2, JP57.3, JP57.4, JP57.5
unnamed: JP51.1, JP51.2, JP51.3, JP51.4, JP51.5
unnamed: JP45.1, JP45.2, JP45.3, JP45.4, JP45.5
unnamed: JP39.1, JP39.2, JP39.3, JP39.4, JP39.5
unnamed: JP31.1, JP31.2, JP31.3, JP31.4, JP31.5
unnamed: JP82.1, JP82.2, JP82.3, JP82.4, JP82.5
unnamed: JP76.1, JP76.2, JP76.3, JP76.4, JP76.5
unnamed: JP70.1, JP70.2, JP70.3, JP70.4, JP70.5
unnamed: JP64.1, JP64.2, JP64.3, JP64.4, JP64.5
unnamed: JP58.1, JP58.2, JP58.3, JP58.4, JP58.5
unnamed: JP52.1, JP52.2, JP52.3, JP52.4, JP52.5
unnamed: JP46.1, JP46.2, JP46.3, JP46.4, JP46.5
unnamed: JP40.1, JP40.2, JP40.3, JP40.4, JP40.5
unnamed: JP32.1, JP32.2, JP32.3, JP32.4, JP32.5
unnamed: JP83.1, JP83.2, JP83.3, JP83.4, JP83.5
unnamed: JP77.1, JP77.2, JP77.3, JP77.4, JP77.5
unnamed: JP71.1, JP71.2, JP71.3, JP71.4, JP71.5
unnamed: JP65.1, JP65.2, JP65.3, JP65.4, JP65.5
unnamed: JP59.1, JP59.2, JP59.3, JP59.4, JP59.5
unnamed: JP53.1, JP53.2, JP53.3, JP53.4, JP53.5
unnamed: JP47.1, JP47.2, JP47.3, JP47.4, JP47.5
unnamed: JP41.1, JP41.2, JP41.3, JP41.4, JP41.5
unnamed: JP33.1, JP33.2, JP33.3, JP33.4, JP33.5
unnamed: JP21.1, JP25.1
unnamed: JP21.2, JP25.2
unnamed: JP21.3, JP25.3
unnamed: JP22.1, JP26.1
unnamed: JP22.2, JP26.2
unnamed: JP22.3, JP26.3
unnamed: JP34.1, JP34.2, JP34.3, JP34.4, JP34.5, JP34.6, JP34.7, JP34.8, JP34.9, JP34.10, JP34.11, JP34.12, JP34.13, JP34.14, JP34.15, JP34.16, JP34.17, JP34.18, JP34.19, JP34.20, JP34.21, JP34.22, JP34.23, JP34.24, JP34.25, JP34.26, JP34.27, JP34.28, JP34.29, JP34.30
unnamed: JP35.1, JP35.2, JP35.3, JP35.4, JP35.5, JP35.6, JP35.7, JP35.8, JP35.9, JP35.10, JP35.11, JP35.12, JP35.13, JP35.14, JP35.15, JP35.16, JP35.17, JP35.18, JP35.19, JP35.20, JP35.21, JP35.22, JP35.23, JP35.24, JP35.25, JP35.26, JP35.27, JP35.28, JP35.29, JP35.30
unnamed: JP23.1, JP27.1
unnamed: JP23.2, JP27.2
unnamed: JP23.3, JP27.3
unnamed: JP91.1, JP95.1
unnamed: JP91.2, JP95.2
unnamed: JP91.3, JP95.3
unnamed: JP92.1, JP96.1
unnamed: JP92.2, JP96.2
unnamed: JP92.3, JP96.3
unnamed: JP93.1, JP97.1
unnamed: JP93.2, JP97.2
unnamed: JP93.3, JP97.3
VCC: JP20.1, JP20.2, JP20.3, JP20.4, JP20.5, JP20.6, JP20.7, JP20.8, JP20.9, JP20.10, JP20.11, JP20.12, JP20.13, JP20.14, JP20.15, JP20.16, JP20.17, JP20.18, JP20.19, JP20.20, JP20.21, JP20.22, JP20.23, JP20.24, JP20.25, JP20.26, JP20.27, JP20.28, JP20.29, JP20.30, JP94.1, JP94.2, JP94.3, JP94.4, JP94.5, JP94.6, JP94.7, JP94.8, JP94.9, JP94.10, JP94.11, JP94.12, JP94.13, JP94.14, JP94.15, JP94.16, JP94.17, JP94.18, JP94.19, JP94.20, JP94.21, JP94.22, JP94.23, JP94.24, JP94.25, JP94.26, JP94.27, JP94.28, JP94.29, JP94.30; also elsewhere on the board

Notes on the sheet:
Byron Jacquot
V10
30-row DIP proto area

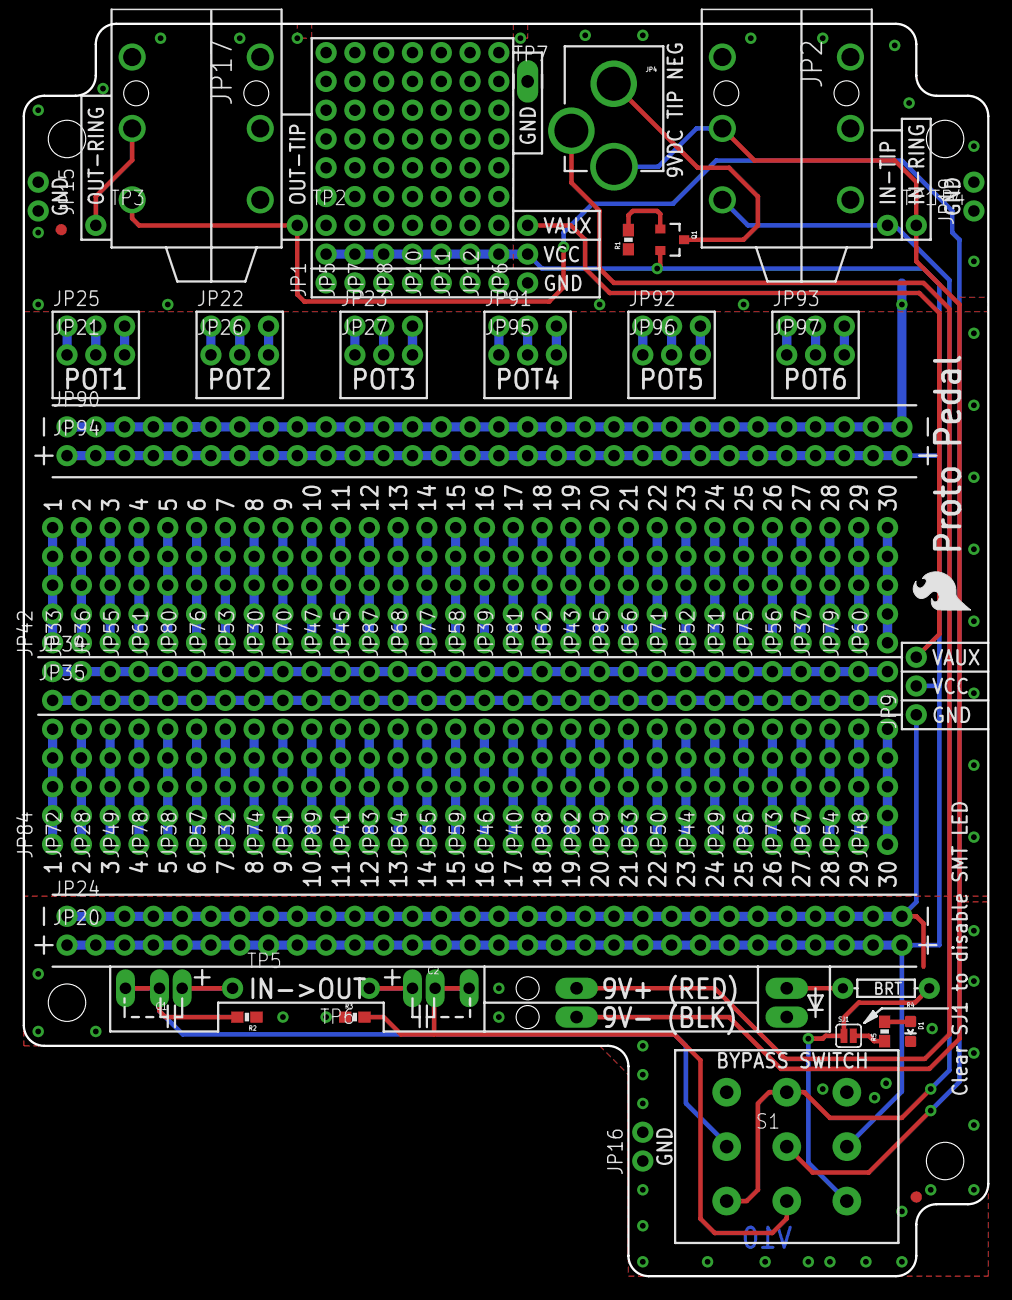
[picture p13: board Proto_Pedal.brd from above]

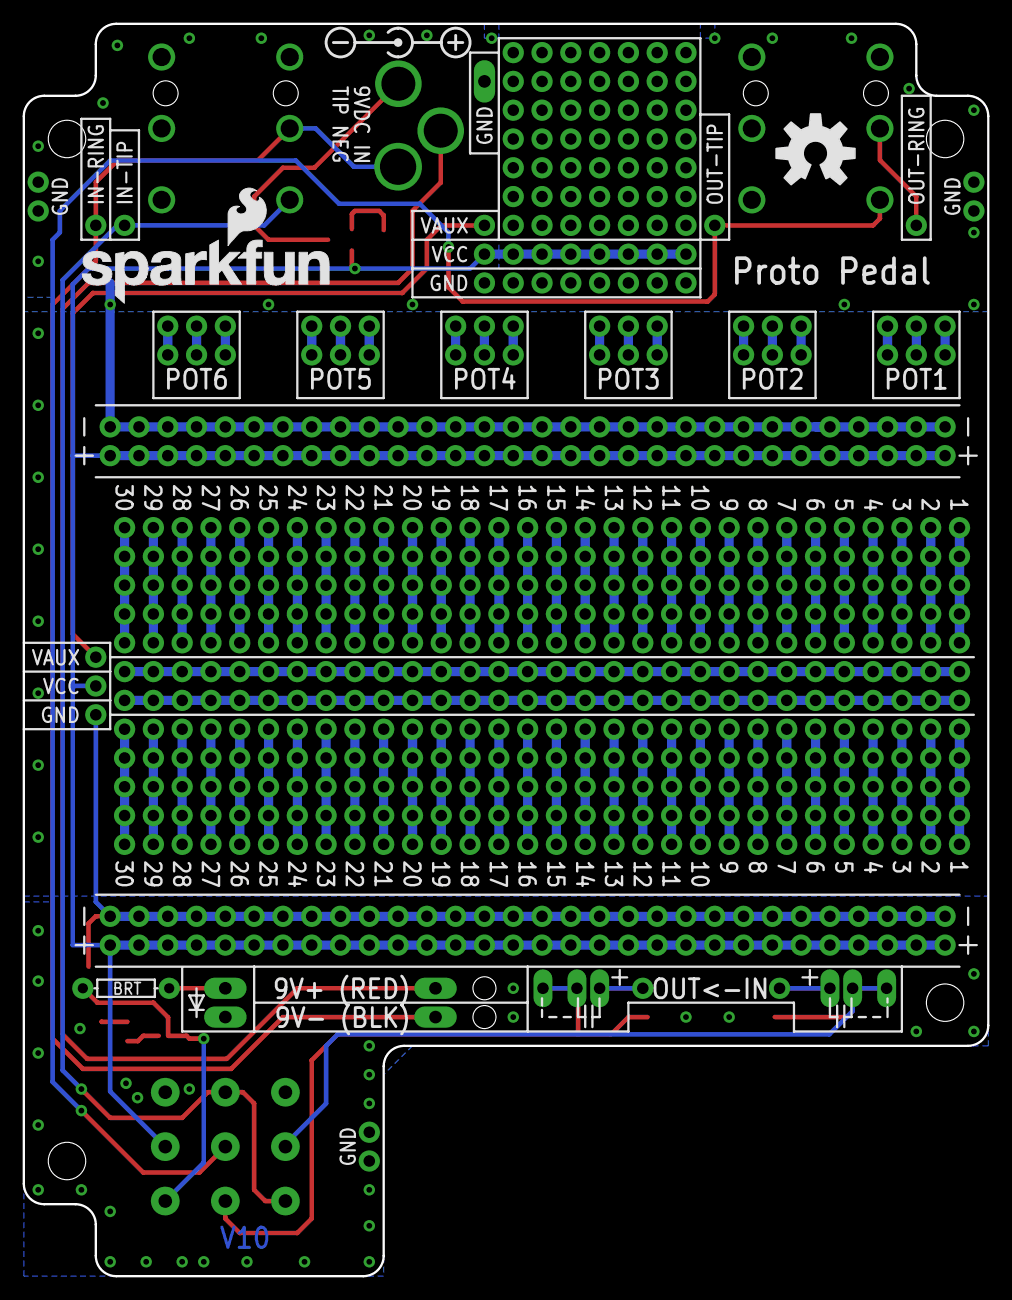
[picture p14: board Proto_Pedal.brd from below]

Board: 2 copper layers, 85.1 x 110.5 mm, 124 parts (3 on the bottom side), 98 nets.

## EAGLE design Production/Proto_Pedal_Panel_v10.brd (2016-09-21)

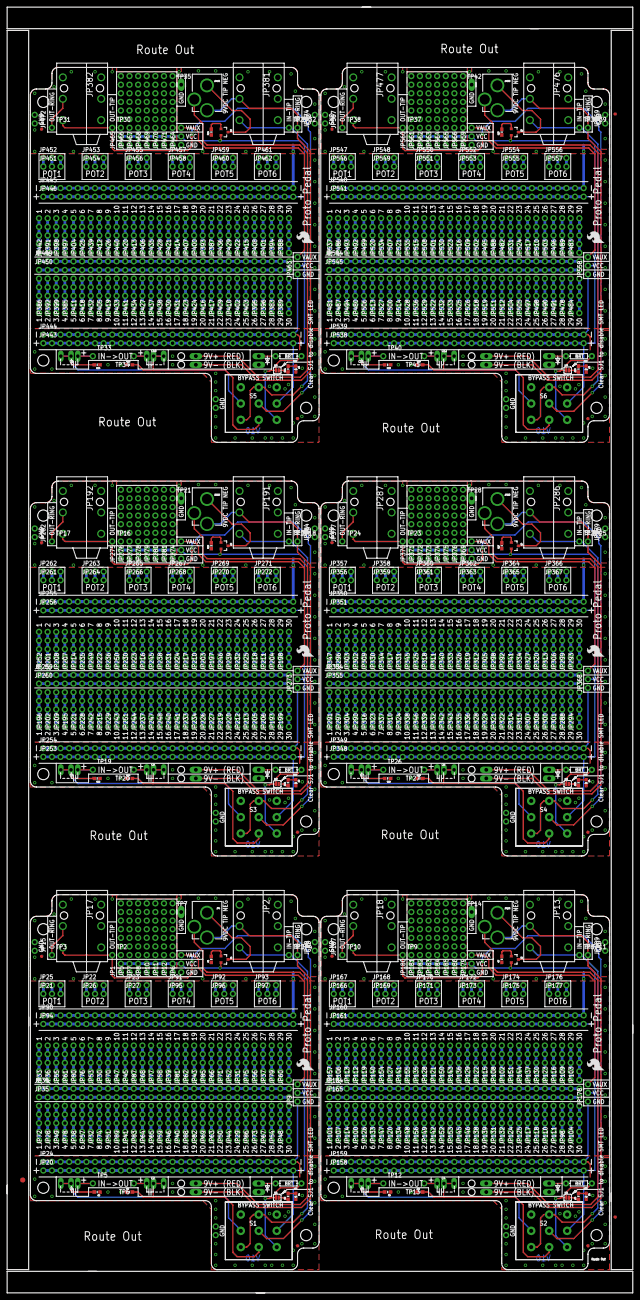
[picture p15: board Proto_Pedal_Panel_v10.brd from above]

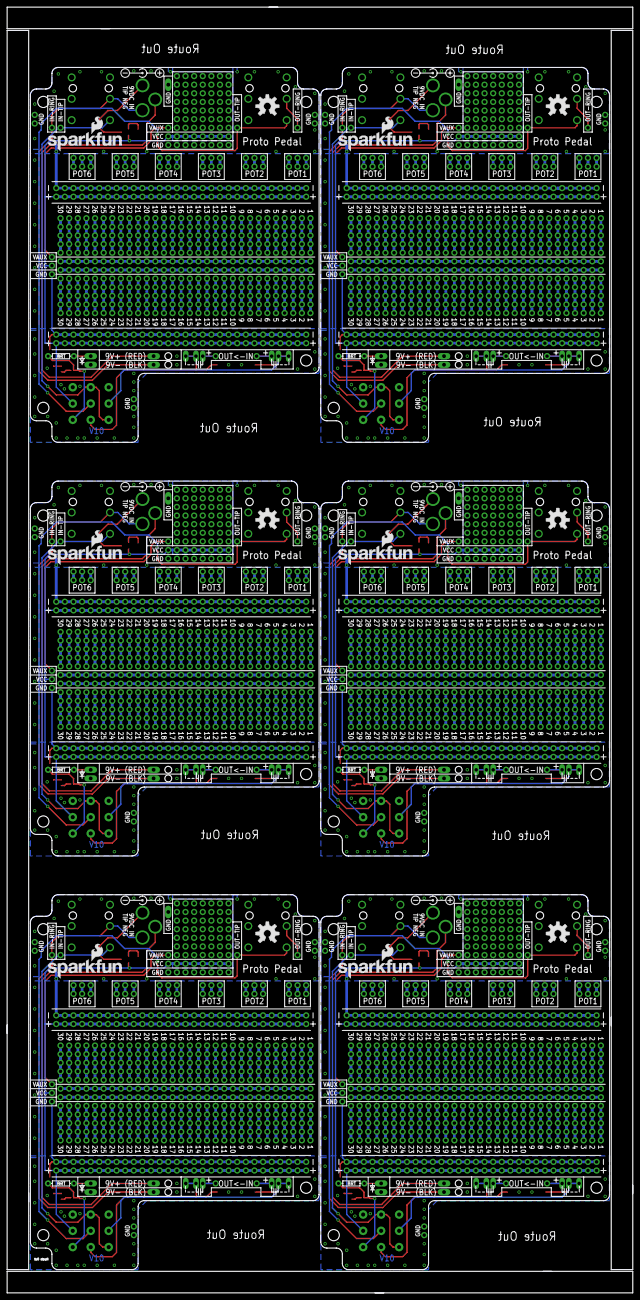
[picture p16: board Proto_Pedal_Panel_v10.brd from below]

Board: 2 copper layers, 184.4 x 379.0 mm, 735 parts (12 on the bottom side), 588 nets.

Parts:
C1, C3, C5, C7, C9, C11: C in; DUAL-CAP
C2, C4, C6, C8, C10, C12: C out; DUAL-CAP
D1, D2, D3, D4, D5, D6: RED; LED-0603
E$1: FIDUCIAL-1.5X3
E$5, E$6: FIDUCIAL-1X2
FID1, FID2, FID3, FID4, FID5, FID6, FID7, FID8, FID9, FID10, FID11, FID12: FIDUCIAL1X2; FIDUCIAL-1X2
JP1, JP5, JP7, JP8, JP10, JP11, JP12, JP180, JP181, JP182, JP183, JP184, JP185, JP186, JP275, JP276, JP277, JP278, JP279, JP280, JP281, JP370, JP371, JP372, JP373, JP374, JP375, JP376, JP465, JP466, JP467, JP468, JP469, JP470, JP471, JP560, JP561, JP562, JP563, JP564, JP565, JP566: 1x9; 1X09_NO_SILK
JP2, JP13, JP191, JP286, JP381, JP476: INPUT JACK; AUDIO-JACK-.25-INCH-HORIZ-PTH
JP3, JP163, JP258, JP353, JP448, JP543: 9VBattery; 1X02_LONGPADS
JP4, JP190, JP285, JP380, JP475, JP570: POWER_JACK_TIP_NEGATIVE; POWER-BARRELJACK-PTH-LOCK-FIXED
JP6, JP9, JP21, JP22, JP23, JP25, JP26, JP27, JP91, JP92, JP93, JP95, JP96, JP97, JP166, JP167, JP168, JP169, JP170, JP171, JP172, JP173, JP174, JP175, JP176, JP177, JP178, JP179, JP261, JP262, JP263, JP264, JP265, JP266, JP267, JP268, JP269, JP270, JP271, JP272, JP273, JP274, JP356, JP357, JP358, JP359, JP360, JP361, JP362, JP363, JP364, JP365, JP366, JP367, JP368, JP369, JP451, JP452, JP453, JP454, JP455, JP456, JP457, JP458, JP459, JP460, JP461, JP462, JP463, JP464, JP546, JP547, JP548, JP549, JP550, JP551, JP552, JP553, JP554, JP555, JP556, JP557, JP558, JP559: 1x3; 1X03_NO_SILK
JP14, JP162, JP257, JP352, JP447, JP542: PTH-LED; 1X02_LONGPADS
JP15, JP16, JP19, JP187, JP188, JP189, JP282, JP283, JP284, JP377, JP378, JP379, JP472, JP473, JP474, JP567, JP568, JP569: 1x2; 1X02_NO_SILK
JP17, JP18, JP192, JP287, JP382, JP477: OUTPUT JACK; AUDIO-JACK-.25-INCH-HORIZ-PTH
JP20, JP24, JP34, JP35, JP90, JP94, JP158, JP159, JP160, JP161, JP164, JP165, JP253, JP254, JP255, JP256, JP259, JP260, JP348, JP349, JP350, JP351, JP354, JP355, JP443, JP444, JP445, JP446, JP449, JP450, JP538, JP539, JP540, JP541, JP544, JP545: 1x30; 1X30_NO_SILK
JP28, JP29, JP30, JP31, JP32, JP33, JP36, JP37, JP38, JP39, JP40, JP41, JP42, JP43, JP44, JP45, JP46, JP47, JP48, JP49, JP50, JP51, JP52, JP53, JP54, JP55, JP56, JP57, JP58, JP59, JP60, JP61, JP62, JP63, JP64, JP65, JP66, JP67, JP68, JP69, JP70, JP71, JP72, JP73, JP74, JP75, JP76, JP77, JP78, JP79, JP80, JP81, JP82, JP83, JP84, JP85, JP86, JP87, JP88, JP98, JP99, JP100, JP101, JP102, JP103, JP104, JP105, JP106, JP107, JP108, JP109, JP110, JP111, JP112, JP113, JP114, JP115, JP116, JP117, JP118, JP119, JP120, JP121, JP122, JP123, JP124, JP125, JP126, JP127, JP128, JP129, JP130, JP131, JP132, JP133, JP134, JP135, JP136, JP137, JP138, JP139, JP140, JP141, JP142, JP143, JP144, JP145, JP146, JP147, JP149, JP150, JP151, JP152, JP153, JP154, JP155, JP156, JP157, JP193, JP194, JP195, JP196, JP197, JP198, JP199, JP200, JP201, JP202, JP203, JP204, JP205, JP206, JP207, JP208, JP209, JP210, JP211, JP212, JP213, JP214, JP215, JP216, JP217, JP218, JP219, JP220, JP221, JP222, JP223, JP224, JP225, JP226, JP227, JP228, JP229, JP230, JP231, JP232, JP233, JP234, JP235, JP236, JP237, JP238, JP239, JP240, JP241, JP242, JP244, JP245, JP246, JP247, JP248, JP249, JP250, JP251, JP252, JP288, JP289, JP290, JP291, JP292, JP293, JP294, JP295, JP296, JP297, JP298, JP299, JP300, JP301, JP302, JP303, JP304, JP305, JP306, JP307, JP308, JP309, JP310, JP311, JP312, JP313, JP314, JP315, JP316, JP317, JP318, JP319, JP320, JP321, JP322, JP323, JP324, JP325, JP326, JP327, JP328, JP329, JP330, JP331, JP332, JP333, JP334, JP335, JP336, JP337, JP339, JP340, JP341, JP342, JP343, JP344, JP345, JP346, JP347, JP383, JP384, JP385, JP386, JP387, JP388, JP389, JP390, JP391, JP392, JP393, JP394, JP395, JP396, JP397, JP398, JP399, JP400, JP401, JP402, JP403, JP404, JP405, JP406, JP407, JP408, JP409, JP410, JP411, JP412, JP413, JP414, JP415, JP416, JP417, JP418, JP419, JP420, JP421, JP422, JP423, JP424, JP425, JP426, JP427, JP428, JP429, JP430, JP431, JP432, JP434, JP435, JP436, JP437, JP438, JP439, JP440, JP441, JP442, JP478, JP479, JP480, JP481, JP482, JP483, JP484, JP485, JP486, JP487, JP488, JP489, JP490, JP491, JP492, JP493, JP494, JP495, JP496, JP497, JP498, JP499, JP500, JP501, JP502, JP503, JP504, JP505, JP506, JP507, JP508, JP509, JP510, JP511, JP512, JP513, JP514, JP515, JP516, JP517, JP518, JP519, JP520, JP521, JP522, JP523, JP524, JP525, JP526, JP527, JP529, JP530, JP531, JP532, JP533, JP534, JP535, JP536, JP537: 1x5; 1X05_NO_SILK
JP89, JP148, JP243, JP338, JP433, JP528: v; 1X05_NO_SILK
LOGO1, LOGO4, LOGO7, LOGO10, LOGO13, LOGO16: SFE_LOGO_NAME_FLAME.2_INCH; SFE_LOGO_NAME_FLAME_.2
LOGO2, LOGO5, LOGO8, LOGO11, LOGO14, LOGO17: OSHW-LOGOL; OSHW-LOGO-L
LOGO3, LOGO6, LOGO9, LOGO12, LOGO15, LOGO18: SFE_LOGO_FLAME.2_INCH; SFE_LOGO_FLAME_.2
Q1, Q2, Q3, Q4, Q5, Q6: 2.5A/30V; SOT23-3
R1, R2, R3, R7, R8, R9, R12, R13, R14, R17, R18, R19, R22, R23, R24, R27, R28, R29: 1M; 0603-RES
R4, R10, R15, R20, R25, R30: BRT; AXIAL-0.3
R5, R6, R11, R16, R21, R26: 1K; 0603-RES
S1, S2, S3, S4, S5, S6: SWITCH-3PDT; STOMP-SWITCH-3PDT
SJ1, SJ2, SJ3, SJ4, SJ5, SJ6: disable LED; PAD-JUMPER-2-NC_BY_PASTE_YES_SILK_FULL_BOX
STANDOFF1, STANDOFF2, STANDOFF3, STANDOFF4, STANDOFF5, STANDOFF6, STANDOFF7, STANDOFF8, STANDOFF9, STANDOFF10, STANDOFF11, STANDOFF12, STANDOFF13, STANDOFF14, STANDOFF15, STANDOFF16, STANDOFF17, STANDOFF18, STANDOFF19, STANDOFF20, STANDOFF21, STANDOFF22, STANDOFF23, STANDOFF24: STAND-OFF
TP1, TP8, TP15, TP22, TP29, TP36: Raw In; 1X01_NO_SILK
TP2, TP9, TP16, TP23, TP30, TP37: Raw Out; 1X01_NO_SILK
TP3, TP10, TP17, TP24, TP31, TP38: Out Ring; 1X01_NO_SILK
TP4, TP11, TP18, TP25, TP32, TP39: In Ring; 1X01_NO_SILK
TP5, TP12, TP19, TP26, TP33, TP40: FX Input; 1X01_NO_SILK
TP6, TP13, TP20, TP27, TP34, TP41: FX Output; 1X01_NO_SILK
TP7, TP14, TP21, TP28, TP35, TP42: Out Ring; 1X01_LONGPAD

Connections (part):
FX_IN: C1.P$2, C1.P$3, R2.2, S1.P$2
FX_IN1: C3.P$2, C3.P$3, R9.2, S2.P$2
FX_IN2: C5.P$2, C5.P$3, R14.2, S3.P$2
FX_IN3: C7.P$2, C7.P$3, R19.2, S4.P$2
FX_IN4: C9.P$2, C9.P$3, R24.2, S5.P$2
FX_IN5: C11.P$2, C11.P$3, R29.2, S6.P$2
FX_OUT: C2.P$2, C2.P$3, R3.2, S1.P$6
FX_OUT1: C4.P$2, C4.P$3, R8.2, S2.P$6
FX_OUT2: C6.P$2, C6.P$3, R13.2, S3.P$6
FX_OUT3: C8.P$2, C8.P$3, R18.2, S4.P$6
FX_OUT4: C10.P$2, C10.P$3, R23.2, S5.P$6
FX_OUT5: C12.P$2, C12.P$3, R28.2, S6.P$6
GND: D1.C, JP1.1, JP2.SLEEVE, JP5.1, JP6.1, JP7.1, JP8.1, JP9.1, JP10.1, JP11.1, JP12.1, JP14.2, JP15.1, JP15.2, JP16.1, JP16.2, JP17.SLEEVE, JP19.1, JP19.2, JP24.1, JP24.2, JP24.3, JP24.4, JP24.5, JP24.6, JP24.7, JP24.8, JP24.9, JP24.10, JP24.11, JP24.12, JP24.13, JP24.14, JP24.15, JP24.16, JP24.17, JP24.18, JP24.19, JP24.20, JP24.21, JP24.22, JP24.23, JP24.24, JP24.25, JP24.26, JP24.27, JP24.28, JP24.29, JP24.30, JP90.1, JP90.2, JP90.3, JP90.4, JP90.5, JP90.6, JP90.7, JP90.8, JP90.9, JP90.10, JP90.11, JP90.12, JP90.13, JP90.14, JP90.15, JP90.16, JP90.17, JP90.18, JP90.19, JP90.20, JP90.21, JP90.22, JP90.23, JP90.24, JP90.25, JP90.26, JP90.27, JP90.28, JP90.29, JP90.30, R1.1, R2.1, R3.1, S1.P$1, TP7.1
GND1: D2.C, JP13.SLEEVE, JP18.SLEEVE, JP159.1, JP159.2, JP159.3, JP159.4, JP159.5, JP159.6, JP159.7, JP159.8, JP159.9, JP159.10, JP159.11, JP159.12, JP159.13, JP159.14, JP159.15, JP159.16, JP159.17, JP159.18, JP159.19, JP159.20, JP159.21, JP159.22, JP159.23, JP159.24, JP159.25, JP159.26, JP159.27, JP159.28, JP159.29, JP159.30, JP160.1, JP160.2, JP160.3, JP160.4, JP160.5, JP160.6, JP160.7, JP160.8, JP160.9, JP160.10, JP160.11, JP160.12, JP160.13, JP160.14, JP160.15, JP160.16, JP160.17, JP160.18, JP160.19, JP160.20, JP160.21, JP160.22, JP160.23, JP160.24, JP160.25, JP160.26, JP160.27, JP160.28, JP160.29, JP160.30, JP162.2, JP178.1, JP179.1, JP180.1, JP181.1, JP182.1, JP183.1, JP184.1, JP185.1, JP186.1, JP187.1, JP187.2, JP188.1, JP188.2, JP189.1, JP189.2, R7.1, R8.1, R9.1, S2.P$1, TP14.1
GND2: D3.C, JP191.SLEEVE, JP192.SLEEVE, JP254.1, JP254.2, JP254.3, JP254.4, JP254.5, JP254.6, JP254.7, JP254.8, JP254.9, JP254.10, JP254.11, JP254.12, JP254.13, JP254.14, JP254.15, JP254.16, JP254.17, JP254.18, JP254.19, JP254.20, JP254.21, JP254.22, JP254.23, JP254.24, JP254.25, JP254.26, JP254.27, JP254.28, JP254.29, JP254.30, JP255.1, JP255.2, JP255.3, JP255.4, JP255.5, JP255.6, JP255.7, JP255.8, JP255.9, JP255.10, JP255.11, JP255.12, JP255.13, JP255.14, JP255.15, JP255.16, JP255.17, JP255.18, JP255.19, JP255.20, JP255.21, JP255.22, JP255.23, JP255.24, JP255.25, JP255.26, JP255.27, JP255.28, JP255.29, JP255.30, JP257.2, JP273.1, JP274.1, JP275.1, JP276.1, JP277.1, JP278.1, JP279.1, JP280.1, JP281.1, JP282.1, JP282.2, JP283.1, JP283.2, JP284.1, JP284.2, R12.1, R13.1, R14.1, S3.P$1, TP21.1
GND3: D4.C, JP286.SLEEVE, JP287.SLEEVE, JP349.1, JP349.2, JP349.3, JP349.4, JP349.5, JP349.6, JP349.7, JP349.8, JP349.9, JP349.10, JP349.11, JP349.12, JP349.13, JP349.14, JP349.15, JP349.16, JP349.17, JP349.18, JP349.19, JP349.20, JP349.21, JP349.22, JP349.23, JP349.24, JP349.25, JP349.26, JP349.27, JP349.28, JP349.29, JP349.30, JP350.1, JP350.2, JP350.3, JP350.4, JP350.5, JP350.6, JP350.7, JP350.8, JP350.9, JP350.10, JP350.11, JP350.12, JP350.13, JP350.14, JP350.15, JP350.16, JP350.17, JP350.18, JP350.19, JP350.20, JP350.21, JP350.22, JP350.23, JP350.24, JP350.25, JP350.26, JP350.27, JP350.28, JP350.29, JP350.30, JP352.2, JP368.1, JP369.1, JP370.1, JP371.1, JP372.1, JP373.1, JP374.1, JP375.1, JP376.1, JP377.1, JP377.2, JP378.1, JP378.2, JP379.1, JP379.2, R17.1, R18.1, R19.1, S4.P$1, TP28.1
GND4: D5.C, JP381.SLEEVE, JP382.SLEEVE, JP444.1, JP444.2, JP444.3, JP444.4, JP444.5, JP444.6, JP444.7, JP444.8, JP444.9, JP444.10, JP444.11, JP444.12, JP444.13, JP444.14, JP444.15, JP444.16, JP444.17, JP444.18, JP444.19, JP444.20, JP444.21, JP444.22, JP444.23, JP444.24, JP444.25, JP444.26, JP444.27, JP444.28, JP444.29, JP444.30, JP445.1, JP445.2, JP445.3, JP445.4, JP445.5, JP445.6, JP445.7, JP445.8, JP445.9, JP445.10, JP445.11, JP445.12, JP445.13, JP445.14, JP445.15, JP445.16, JP445.17, JP445.18, JP445.19, JP445.20, JP445.21, JP445.22, JP445.23, JP445.24, JP445.25, JP445.26, JP445.27, JP445.28, JP445.29, JP445.30, JP447.2, JP463.1, JP464.1, JP465.1, JP466.1, JP467.1, JP468.1, JP469.1, JP470.1, JP471.1, JP472.1, JP472.2, JP473.1, JP473.2, JP474.1, JP474.2, R22.1, R23.1, R24.1, S5.P$1, TP35.1
GND5: D6.C, JP476.SLEEVE, JP477.SLEEVE, JP539.1, JP539.2, JP539.3, JP539.4, JP539.5, JP539.6, JP539.7, JP539.8, JP539.9, JP539.10, JP539.11, JP539.12, JP539.13, JP539.14, JP539.15, JP539.16, JP539.17, JP539.18, JP539.19, JP539.20, JP539.21, JP539.22, JP539.23, JP539.24, JP539.25, JP539.26, JP539.27, JP539.28, JP539.29, JP539.30, JP540.1, JP540.2, JP540.3, JP540.4, JP540.5, JP540.6, JP540.7, JP540.8, JP540.9, JP540.10, JP540.11, JP540.12, JP540.13, JP540.14, JP540.15, JP540.16, JP540.17, JP540.18, JP540.19, JP540.20, JP540.21, JP540.22, JP540.23, JP540.24, JP540.25, JP540.26, JP540.27, JP540.28, JP540.29, JP540.30, JP542.2, JP558.1, JP559.1, JP560.1, JP561.1, JP562.1, JP563.1, JP564.1, JP565.1, JP566.1, JP567.1, JP567.2, JP568.1, JP568.2, JP569.1, JP569.2, R27.1, R28.1, R29.1, S6.P$1, TP42.1
LEDA: JP14.1, R4.P$2
LEDA1: JP162.1, R10.P$2
LEDA2: JP257.1, R15.P$2
LEDA3: JP352.1, R20.P$2
LEDA4: JP447.1, R25.P$2
LEDA5: JP542.1, R30.P$2
unnamed: JP84.1, JP84.2, JP84.3, JP84.4, JP84.5
unnamed: JP85.1, JP85.2, JP85.3, JP85.4, JP85.5
unnamed: JP86.1, JP86.2, JP86.3, JP86.4, JP86.5
unnamed: JP87.1, JP87.2, JP87.3, JP87.4, JP87.5
unnamed: JP54.1, JP54.2, JP54.3, JP54.4, JP54.5
unnamed: JP88.1, JP88.2, JP88.3, JP88.4, JP88.5
unnamed: JP78.1, JP78.2, JP78.3, JP78.4, JP78.5
unnamed: JP72.1, JP72.2, JP72.3, JP72.4, JP72.5
unnamed: JP66.1, JP66.2, JP66.3, JP66.4, JP66.5
unnamed: JP60.1, JP60.2, JP60.3, JP60.4, JP60.5
unnamed: JP48.1, JP48.2, JP48.3, JP48.4, JP48.5
unnamed: JP42.1, JP42.2, JP42.3, JP42.4, JP42.5
unnamed: JP36.1, JP36.2, JP36.3, JP36.4, JP36.5
unnamed: JP28.1, JP28.2, JP28.3, JP28.4, JP28.5
unnamed: JP89.1, JP89.2, JP89.3, JP89.4, JP89.5
unnamed: JP79.1, JP79.2, JP79.3, JP79.4, JP79.5
unnamed: JP73.1, JP73.2, JP73.3, JP73.4, JP73.5
unnamed: JP67.1, JP67.2, JP67.3, JP67.4, JP67.5
unnamed: JP61.1, JP61.2, JP61.3, JP61.4, JP61.5
unnamed: JP55.1, JP55.2, JP55.3, JP55.4, JP55.5
unnamed: JP49.1, JP49.2, JP49.3, JP49.4, JP49.5
unnamed: JP43.1, JP43.2, JP43.3, JP43.4, JP43.5
unnamed: JP37.1, JP37.2, JP37.3, JP37.4, JP37.5
unnamed: JP29.1, JP29.2, JP29.3, JP29.4, JP29.5
unnamed: D1.A, R5.2
unnamed: JP80.1, JP80.2, JP80.3, JP80.4, JP80.5
unnamed: JP74.1, JP74.2, JP74.3, JP74.4, JP74.5
unnamed: JP68.1, JP68.2, JP68.3, JP68.4, JP68.5
unnamed: JP62.1, JP62.2, JP62.3, JP62.4, JP62.5
unnamed: JP56.1, JP56.2, JP56.3, JP56.4, JP56.5
unnamed: JP50.1, JP50.2, JP50.3, JP50.4, JP50.5
unnamed: JP44.1, JP44.2, JP44.3, JP44.4, JP44.5
unnamed: JP38.1, JP38.2, JP38.3, JP38.4, JP38.5
unnamed: JP30.1, JP30.2, JP30.3, JP30.4, JP30.5
unnamed: R4.P$1, S1.P$9, SJ1.1
unnamed: JP81.1, JP81.2, JP81.3, JP81.4, JP81.5
unnamed: JP75.1, JP75.2, JP75.3, JP75.4, JP75.5
unnamed: JP69.1, JP69.2, JP69.3, JP69.4, JP69.5
unnamed: JP63.1, JP63.2, JP63.3, JP63.4, JP63.5
unnamed: JP57.1, JP57.2, JP57.3, JP57.4, JP57.5
unnamed: JP51.1, JP51.2, JP51.3, JP51.4, JP51.5
unnamed: JP45.1, JP45.2, JP45.3, JP45.4, JP45.5
unnamed: JP39.1, JP39.2, JP39.3, JP39.4, JP39.5
unnamed: JP31.1, JP31.2, JP31.3, JP31.4, JP31.5
unnamed: JP3.1, JP4.SLEEVE-NORMAL
unnamed: JP82.1, JP82.2, JP82.3, JP82.4, JP82.5
unnamed: JP76.1, JP76.2, JP76.3, JP76.4, JP76.5
unnamed: JP70.1, JP70.2, JP70.3, JP70.4, JP70.5
unnamed: JP64.1, JP64.2, JP64.3, JP64.4, JP64.5
unnamed: JP58.1, JP58.2, JP58.3, JP58.4, JP58.5
unnamed: JP52.1, JP52.2, JP52.3, JP52.4, JP52.5
unnamed: JP46.1, JP46.2, JP46.3, JP46.4, JP46.5
unnamed: JP40.1, JP40.2, JP40.3, JP40.4, JP40.5
unnamed: JP32.1, JP32.2, JP32.3, JP32.4, JP32.5
unnamed: JP2.RING, JP3.2, JP4.TIP, TP4.1
unnamed: JP83.1, JP83.2, JP83.3, JP83.4, JP83.5
unnamed: JP77.1, JP77.2, JP77.3, JP77.4, JP77.5
unnamed: JP71.1, JP71.2, JP71.3, JP71.4, JP71.5
unnamed: JP65.1, JP65.2, JP65.3, JP65.4, JP65.5
unnamed: JP59.1, JP59.2, JP59.3, JP59.4, JP59.5
unnamed: JP53.1, JP53.2, JP53.3, JP53.4, JP53.5
unnamed: JP47.1, JP47.2, JP47.3, JP47.4, JP47.5
unnamed: JP41.1, JP41.2, JP41.3, JP41.4, JP41.5
unnamed: JP33.1, JP33.2, JP33.3, JP33.4, JP33.5
unnamed: R5.1, SJ1.2
unnamed: JP17.RING, TP3.1
unnamed: C1.P$1, TP5.1
unnamed: C2.P$1, TP6.1
unnamed: JP13.TIP, S2.P$3, S2.P$4, TP8.1
unnamed: JP2.TIP, S1.P$3, S1.P$4, TP1.1
unnamed: JP17.TIP, S1.P$5, TP2.1
unnamed: JP18.TIP, S2.P$5, TP9.1
unnamed: JP98.1, JP98.2, JP98.3, JP98.4, JP98.5
unnamed: JP100.1, JP100.2, JP100.3, JP100.4, JP100.5
unnamed: Q1.1, R1.2
unnamed: JP101.1, JP101.2, JP101.3, JP101.4, JP101.5
unnamed: JP21.1, JP25.1
unnamed: JP102.1, JP102.2, JP102.3, JP102.4, JP102.5
unnamed: JP21.2, JP25.2
unnamed: JP103.1, JP103.2, JP103.3, JP103.4, JP103.5
unnamed: JP21.3, JP25.3
unnamed: JP104.1, JP104.2, JP104.3, JP104.4, JP104.5
unnamed: JP22.1, JP26.1
unnamed: JP105.1, JP105.2, JP105.3, JP105.4, JP105.5
unnamed: JP22.2, JP26.2
unnamed: JP106.1, JP106.2, JP106.3, JP106.4, JP106.5
unnamed: JP22.3, JP26.3
unnamed: JP107.1, JP107.2, JP107.3, JP107.4, JP107.5
unnamed: JP34.1, JP34.2, JP34.3, JP34.4, JP34.5, JP34.6, JP34.7, JP34.8, JP34.9, JP34.10, JP34.11, JP34.12, JP34.13, JP34.14, JP34.15, JP34.16, JP34.17, JP34.18, JP34.19, JP34.20, JP34.21, JP34.22, JP34.23, JP34.24, JP34.25, JP34.26, JP34.27, JP34.28, JP34.29, JP34.30
unnamed: JP35.1, JP35.2, JP35.3, JP35.4, JP35.5, JP35.6, JP35.7, JP35.8, JP35.9, JP35.10, JP35.11, JP35.12, JP35.13, JP35.14, JP35.15, JP35.16, JP35.17, JP35.18, JP35.19, JP35.20, JP35.21, JP35.22, JP35.23, JP35.24, JP35.25, JP35.26, JP35.27, JP35.28, JP35.29, JP35.30
unnamed: JP23.1, JP27.1
unnamed: JP109.1, JP109.2, JP109.3, JP109.4, JP109.5
unnamed: JP23.2, JP27.2
unnamed: JP23.3, JP27.3
unnamed: JP91.1, JP95.1
unnamed: JP91.2, JP95.2
unnamed: JP91.3, JP95.3
unnamed: JP92.1, JP96.1
unnamed: JP92.2, JP96.2
unnamed: JP92.3, JP96.3
unnamed: JP93.1, JP97.1
unnamed: JP93.2, JP97.2
unnamed: JP93.3, JP97.3
unnamed: JP110.1, JP110.2, JP110.3, JP110.4, JP110.5
unnamed: JP111.1, JP111.2, JP111.3, JP111.4, JP111.5
unnamed: JP112.1, JP112.2, JP112.3, JP112.4, JP112.5
unnamed: JP113.1, JP113.2, JP113.3, JP113.4, JP113.5
unnamed: JP114.1, JP114.2, JP114.3, JP114.4, JP114.5
unnamed: JP115.1, JP115.2, JP115.3, JP115.4, JP115.5
unnamed: JP116.1, JP116.2, JP116.3, JP116.4, JP116.5
unnamed: JP117.1, JP117.2, JP117.3, JP117.4, JP117.5
unnamed: JP119.1, JP119.2, JP119.3, JP119.4, JP119.5
unnamed: JP120.1, JP120.2, JP120.3, JP120.4, JP120.5
unnamed: JP121.1, JP121.2, JP121.3, JP121.4, JP121.5
unnamed: JP122.1, JP122.2, JP122.3, JP122.4, JP122.5
unnamed: JP123.1, JP123.2, JP123.3, JP123.4, JP123.5
unnamed: JP124.1, JP124.2, JP124.3, JP124.4, JP124.5
unnamed: JP125.1, JP125.2, JP125.3, JP125.4, JP125.5
unnamed: JP126.1, JP126.2, JP126.3, JP126.4, JP126.5
unnamed: JP127.1, JP127.2, JP127.3, JP127.4, JP127.5
unnamed: JP129.1, JP129.2, JP129.3, JP129.4, JP129.5
unnamed: JP130.1, JP130.2, JP130.3, JP130.4, JP130.5
unnamed: JP131.1, JP131.2, JP131.3, JP131.4, JP131.5
unnamed: JP132.1, JP132.2, JP132.3, JP132.4, JP132.5
unnamed: JP133.1, JP133.2, JP133.3, JP133.4, JP133.5
unnamed: JP134.1, JP134.2, JP134.3, JP134.4, JP134.5
unnamed: JP135.1, JP135.2, JP135.3, JP135.4, JP135.5
unnamed: JP136.1, JP136.2, JP136.3, JP136.4, JP136.5
unnamed: JP137.1, JP137.2, JP137.3, JP137.4, JP137.5
unnamed: JP139.1, JP139.2, JP139.3, JP139.4, JP139.5
unnamed: JP140.1, JP140.2, JP140.3, JP140.4, JP140.5
unnamed: JP141.1, JP141.2, JP141.3, JP141.4, JP141.5
unnamed: JP142.1, JP142.2, JP142.3, JP142.4, JP142.5
unnamed: JP143.1, JP143.2, JP143.3, JP143.4, JP143.5
unnamed: JP144.1, JP144.2, JP144.3, JP144.4, JP144.5
unnamed: JP145.1, JP145.2, JP145.3, JP145.4, JP145.5
unnamed: JP146.1, JP146.2, JP146.3, JP146.4, JP146.5
unnamed: JP147.1, JP147.2, JP147.3, JP147.4, JP147.5
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

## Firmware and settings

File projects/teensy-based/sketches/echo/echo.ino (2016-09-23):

/* Teensy pedal echo demo sketch.
 *  
 * A tape-delay inspired delay sketch, with heavy filtering and 
 * subtle distortion in the feedback loop.
 *  
 * Copyright (c) 2016, Byron Jacquot, SparkFun Electronics
 * SparkFun code, firmware, and software is released under 
 * the MIT License(http://opensource.org/licenses/MIT).
 *
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
 */


#include <Audio.h>
#include <Wire.h>
#include <SPI.h>
#include <SD.h>
#include <SerialFlash.h>

#include "mod-delay.h"
#include "cubic-distort.h"

/***************/

AudioSynthNoiseWhite noise;

AudioMixer4              inmix;
AudioSynthWaveformDc     dlyctrl;
AudioEffectModDelay      xdly;
AudioFilterStateVariable delayfilthp;
AudioFilterStateVariable delayfiltlp;

AudioOutputI2S       i2s1;           
AudioInputI2S        i2s2;           
AudioControlSGTL5000 sgtl5000_1;

/***************/

////AudioConnection     patchCord01(i2s2, 0, infilt, 0);
////AudioConnection     patchCord02(infilt, 0, inmix, 0);
AudioConnection     patchCord01(i2s2, 0, inmix, 0);
AudioConnection     patchCord03(noise, 0, inmix, 2);
AudioConnection     patchCord04(inmix, 0, xdly, 0);
AudioConnection     patchCord06(xdly, 0, delayfilthp, 0);
AudioConnection     patchCord07(delayfilthp, 2, delayfiltlp, 0);
AudioConnection     patchCord05(delayfiltlp, 0, inmix, 1);

AudioConnection     patchCord100(dlyctrl,0, xdly, 1);

AudioConnection     patchCord11(inmix, 0, i2s1, 0);
AudioConnection     patchCord12(inmix, 0, i2s1, 1);

/***************/


// This is about max (97%!) for internal RAM
static const uint32_t LEN = 0x06800;
int16_t delaybuf[LEN];

uint32_t next;


/***************/

void param_update()
{
  uint16_t value;
#if 0
  // If you don't have panel controls, here are prebaked settings

  inmix.gain(1, 0.7);
  dlyctrl.amplitude(1.0);
  delayfilthp.frequency(150);
  delayfilthp.resonance(1.0);
  delayfiltlp.frequency(1500);
  

#else
  // ADC gives us 10 bits of data, but the bottom two are a bit noisy.
  // So we'll make them always 1's with a series of bitwise or with 3 ( | 0x03 ).

  static uint16_t last_time;

  // Set feedback level
  value = analogRead(A7);
  inmix.gain(1, (float)((value|0x03)*1.2/0x3ff));

  value = analogRead(A1);
  value |= 0x03;
  if( value != last_time)
  {
    dlyctrl.amplitude((float)(value )/0x3ff, 200);
    last_time = value;
  }
  //dlyctrl.amplitude(0.5);

  value = analogRead(A2);
  // 10730 = 10230 + 500
  delayfiltlp.frequency(500 + ((value| 0x03)*10));

  value = analogRead(A6);
  delayfilthp.frequency(100 + (value| 0x03));

  value = analogRead(A3);
  delayfilthp.resonance(((float)(value|0x03)/0x3ff)* 2);
  //delayfiltlp.resonance((float)value/0x3ff);

#endif  
}



void setup() {
  // put your setup code here, to run once:

  Serial.begin(115200);
  Serial.println("Setup");

  AudioMemory(20);

  AudioNoInterrupts();

  // Adding in some noise can trigger spontaneous breakaway.
  //noise.amplitude(0.025);

  inmix.gain(0, 1.0);
  //inmix.gain(1, 0.9);// set by knob
  inmix.gain(2, 0.02);

  //infilt.setLowpass(0, 2500, 0.7);
  //infilt.setHighpass(1, 40, 0.7);

  xdly.setbuf(LEN, delaybuf);

  //delayfiltlp.resonance(2.0);
  
  sgtl5000_1.enable();
  sgtl5000_1.inputSelect(AUDIO_INPUT_LINEIN );

  sgtl5000_1.lineInLevel(0,2);
  sgtl5000_1.lineOutLevel(13);

  // Testing...these appear to address a little background noise...
  sgtl5000_1.muteHeadphone();
  sgtl5000_1.adcHighPassFilterDisable();
  sgtl5000_1.audioProcessorDisable();

  AudioInterrupts();

  next = millis() + 1000;

  Serial.println("Setup complete.");

}



void loop() {
  // put your main code here, to run repeatedly:
  static bool next_on = true;

  static uint32_t count = 0;

  param_update();

  if(millis() > next)
  {
    next += 125;
    count++;

    Serial.print("Diagnostics: ");
    Serial.print(" max, buffs: ");
    Serial.print(AudioProcessorUsageMax());
    Serial.print(" ");
    Serial.println(AudioMemoryUsageMax());
    AudioProcessorUsageMaxReset();
    xdly.inspect();
  }

}

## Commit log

2014-09-18 Initial Commit
    Boilderplate and WIP PCB files
    [Proto_Pedal.brd, Proto_Pedal.sch]
2014-09-22 PCB Ready for protos
    [Proto_Pedal.brd, Proto_Pedal.sch]
2015-10-12 WIP.
    Redid bypass switch to 3PDT component with multiple gates.
    Removed questionable LED circuit, replaced with an actual switch
    section.
    [Proto_Pedal.brd, Proto_Pedal.sch]
2015-11-03 More WIP
    Many more changes based on prototype review.
    -Tip-negative power input.
    -uncommited proto space for power regulation.
    -Rail splitter removed
    -Strain relief near 9V snap
    -Some test points on i/O jacks
    [Proto_Pedal.brd, Proto_Pedal.sch]
2015-11-04 More WIP.
    -Columns labeled.
    -Traces complete.
    -Text & silk more complete & organized.
    [Proto_Pedal.brd]
2015-11-05 More WIP
    Much cleanup for review soon.
    [Proto_Pedal.brd, Proto_Pedal.sch]
2015-11-06 Preparing for review
    Lots of little touch ups.
    [Proto_Pedal.brd, Proto_Pedal.sch]
2015-11-10 Updates after group review.
    PTH power connector.
    PTH LED bias resistor.
    [Proto_Pedal.brd, Proto_Pedal.sch]
2015-11-13 Relaxed design to use standard DRU
    Fixed funny pour shapes
    Relocated a couple traces
    Renumbered parts
    [Proto_Pedal.brd, Proto_Pedal.sch]
2015-11-19 A couple of fixes after review.
    Fixed spelling of sililar.
    One piece of top silk had fallen to bottom - now corrected.
    [Proto_Pedal.brd, Proto_Pedal.sch]
2016-03-11 added model of hammond style enclosure with cutouts for jacks and LED
    [CaseWCutoutsModel.FCStd]
2016-03-21 Updates based on proto evaluation.
    Usability & fit'n'finish issues solved.
    [Proto_Pedal.brd, Proto_Pedal.sch]
2016-03-22 PCB updates after Marshall looked closer.
    A new more nits cleaned up.
    [Proto_Pedal.brd, Proto_Pedal.sch]
2016-03-22 Tweaks from checklist.
    - and + signs on rails are a bit smaller.
    +'s next to C1 and C2 were overlapping bare copper.
    Version bumped to V03.
    [Proto_Pedal.brd, Proto_Pedal.sch]
2016-03-25 Moved ground hole to center, made r=1.65mm, d=3.3 for 1/8 inch bit to cut.
    [CaseWCutoutsModel.FCStd]
2016-05-02 Adding solidworks drawing & preview render.
    [case_w_cutouts_model.SLDPRT]
2016-06-14 Silkscreen touchups from V03 proto.
    Prepping for redboard review.
    Rolling version to V10.
    [Proto_Pedal.brd, Proto_Pedal.sch]
2016-06-20 Updates to board following group review.
    Added bottom-layer traces on I/O caps.
    Updated dimensions for standoff holes.
    [Proto_Pedal.brd]
2016-06-20 Checklist review changes
    Bumping silk outlines for connectors to .008" (up from .005)
    [Proto_Pedal.brd, Proto_Pedal.sch]
2016-06-20 Fixing what Eric found in review.
    -I/O coupling caps now have similar trace arrangements.
    -Second page of Schem bumped to V10.
    [Proto_Pedal.brd, Proto_Pedal.sch]
2016-06-23 created panel v10
    [Proto_Pedal_Panel_v10.brd]
2016-09-21 Adding Throughput sketch for Teensy
    Should pass audio input to output, and print serial disgnostics of the 5
    ADC inputs.
2016-09-22 Adding echo sketch.
    Still a bit messy, but need to check it in.
    [shaper1.ods]
2016-09-23 Adding solidworks part for enclosure
    [case_w_cutouts_model_2.SLDPRT]
2016-09-23 Adding files for gyrator EQ
    [gyrator-eq.brd, gyrator-eq.sch]
2016-09-23 Adding files for Teensy projects
    [teensy-pedal-example.brd, teensy-pedal-example.sch, teensy-pedal.brd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]

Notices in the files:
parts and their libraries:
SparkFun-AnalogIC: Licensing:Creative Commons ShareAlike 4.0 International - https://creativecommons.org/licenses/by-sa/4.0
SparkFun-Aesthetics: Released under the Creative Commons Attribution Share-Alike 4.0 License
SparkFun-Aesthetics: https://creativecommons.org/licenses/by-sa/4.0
